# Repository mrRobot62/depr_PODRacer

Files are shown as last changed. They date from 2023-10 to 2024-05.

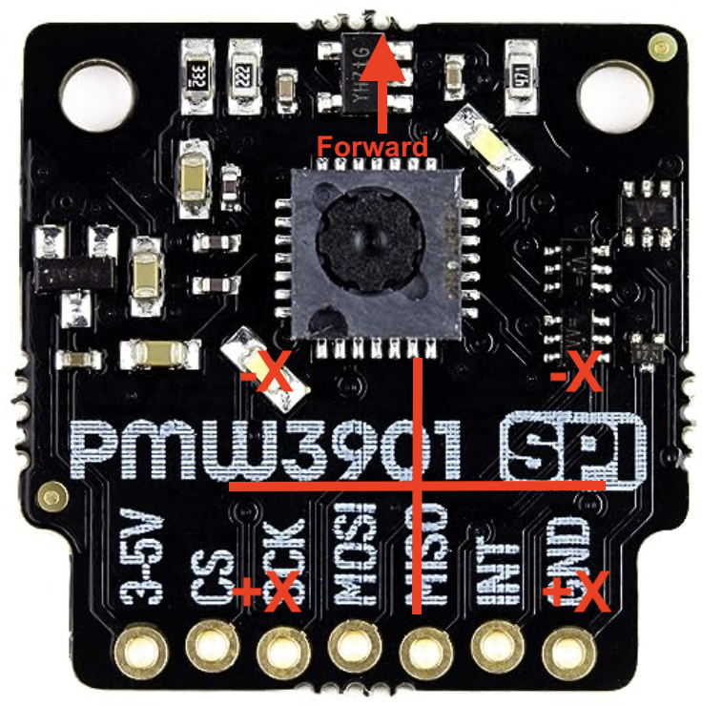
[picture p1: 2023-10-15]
doc/pmw3901_dir.png

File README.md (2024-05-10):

# OUTDATED
I decided to start more or less from scratch new. Current PODRacer-FW is implemented here: https://github.com/mrRobot62/PODRacerV3.git

# POD-Racer
```
.---------------------------------------------------------.
|_______________________________                          |
|___  __ \_  __ \__  __ \__  __ \_____ ___________________|
|__  /_/ /  / / /_  / / /_  /_/ /  __ `/  ___/  _ \_  ___/|
|_  ____// /_/ /_  /_/ /_  _, _// /_/ // /__ /  __/  /    |
|/_/     \____/ /_____/ /_/ |_| \__,_/ \___/ \___//_/     |
'---------------------------------------------------------'
```

# Hardware
## Transmitter (Taranis/TBS)
Channel configuration
- CH0 : roll axis		-> gimbal roll
- CH1 : pitch axis		-> gimbal pitch
- CH3 : FMS Impeller		-> gimbal throttle
- CH4 : yaw axis			-> gimbal yaw
- CH5 : arming/disarming-> switch
- CH6 : -> switch
- CH7 : -> switch
- CH8 : Hovering via POT S1	
## ToF-Sensors
- PMW3901 
- VL53LX1
- TF Mini LIDAR

# Software
# Arduino IDE 2.2.1

## ESP 32 - Datatype size
|Type|DataType|size (bytes)|
|---|---|:-:|
|Bool|bool|1|
|Char|char/int8-t|1|
|signed byte|int8_t|1|
|unsigned byte|uint8_t|1|
|int|int16_t|2|
|uint|uint16_t|2|
|long|long/int32_t|4|
|unsigned long|uint32_t|4|
|long64|int64_t|8|
|unsigned long64|uint64_t|8|
|Float|float|4/(8)|
|Double|double|8|
|String|char */String|variable|
|Bytes|uint8_t|variable|
||||

## Blackbox 
To store flight data, we use a SDCard with 4-8GB size. Every task use an internal data structure (every task use the same structure). This structure is used to store the data in a blackbox_<seqnumber>.bbd.

If PODRacer is armed a new blackbox file will be created, if disarmed the file is stored and closed on disk.
If disarming was not available (e.g. power off) the file is corrupted and not usable.

### Datetype-Struct (for every tasks usable)
```
#define NUMBER_CHANNELS 16
#define DATA_SIZE 8
typedef struct {
  uint16_t header;				   // fix to 0xFEEF
  long millis;                     // milliseconds
  // data
  uint8_t task_id;                 // produces by task-id
  uint8_t updated;                 // set by tasks
  uint8_t failsafe;                // set by receiver
  uint8_t lost_frame;              // set by receiver
  uint8_t levelA;                  // 1=normal, 2=depth (1=default)
  uint8_t levelB;                  // group_id 0=misc, 1=hover, 2=surfacedist, 3=OpticalFlow, 4=mixer, 
  uint16_t ch[NUMBER_CHANNELS];    // channel data (0=ch1, 1=ch2, 2=ch3, ...)
  //uint16_t ch_w[NUMBER_CHANNELS];// channel data (0=ch1, 1=ch2, 2=ch3, ...) WRITE 
  long ldata[DATA_SIZE];           // an be used for long values  
  double fdata[DATA_SIZE];         // can be used for float values
  double pid_rpyth[DATA_SIZE];     //(R/P/Y/T/H);
  uint16_t lock;                   // fix to 0xFF
  uint16_t crc;
} BlackBoxStruct;

typedef union {
  BlackBoxStruct data;
  uint8_t bytes [sizeof(BlackBoxStruct)];
} BBD;
```

Dump from a simulated data structure with fixed values
```
  bbd->data.header = 0xFEEF;
  bbd->data.millis = millis();
  bbd->data.task_id = 0x0A;
  bbd->data.updated = 0x0B;
  bbd->data.failsafe = 0xF0;
  bbd->data.lost_frame = 0xC0;
  bbd->data.groupA=0xB0;
  bbd->data.groupB=0xA0;
  bbd->data.crc = 0;  // for initializing!!!!! 
  for (uint8_t i=NUMBER_CHANNELS; i--;) {
    bbd->data.ch[i] = 1450;
  }
  for (uint8_t i=DATA_SIZE; i--;) {
    bbd->data.ldata[i] = -500;
    bbd->data.fdata[i] = 3.1415;
    bbd->data.pid_rpyth[i] = 1.0;
  }
  bbd->data.lock = 0xFF;
  uint16_t crc = FCRC16.ccitt((uint8_t*)bbd->bytes, sizeof(bbd));
  bbd->data.crc = crc;  
  sprintf(buffer, "CCITT-CRC: 0x%X", crc);
  Serial.println(buffer);
```
To understand how the struct is aligned you should understand [Data structure alignment](https://en.wikipedia.org/wiki/Data_structure_alignment)

### Short description
Bytes are stored with little endian. (LSB first, than MSB)

|Position| Data| Type |Padding| Info|
|---|:-:|:-:|:-:|---|
|0-1|EF FE|uint16_t|yes|header 2 bytes with padding|
|2-3|00 00|-|padding|2 padding bytes for uint16_t|
|4-7|1D 02 00 00|long|no|millis()|
|8-13|0A 0B F0 C0 B0 A0|uint8_t|no|7 Bytes uint8_t (task_id...groupB)|
|14-45|AA 05....|uint16_t|yes|16 channels a 2 Bytess, set to 1450(dec) 0x05AA|
|46,47|00 00|-|padding|2 padding bytes for uint16_t||
|48-79|0C FE FF FF|long|no|4 Bytes LData. Note: array of 8 long values|
|80-143|6F 12 83 C0 CA 21 09 40|double|no|8 Bytes FData. Note: array of 8 doubles values|
|144-207|00 00 00 00 00 00 F0 3F|double|no|8Bytes per pid_rpyth. Note: array of 8 doubles |
|208|FF|uint8_t|yes|lock byte|
|209|00|no|padding|1 padding byte|
|210-211|97 2C|uint16_t|yes|2 Bytes CRC|
|212-215|00 00 00 00 |-|padding| 4 Bytes padding|

```
-- dump-start (216 bytes) -------------------------
EF FE 00 00 1D 02 00 00 0A 0B F0 C0 B0 A0 AA 05 
AA 05 AA 05 AA 05 AA 05 AA 05 AA 05 AA 05 AA 05 
AA 05 AA 05 AA 05 AA 05 AA 05 AA 05 AA 05 00 00 
0C FE FF FF 0C FE FF FF 0C FE FF FF 0C FE FF FF 
0C FE FF FF 0C FE FF FF 0C FE FF FF 0C FE FF FF 
6F 12 83 C0 CA 21 09 40 6F 12 83 C0 CA 21 09 40 
6F 12 83 C0 CA 21 09 40 6F 12 83 C0 CA 21 09 40 
6F 12 83 C0 CA 21 09 40 6F 12 83 C0 CA 21 09 40 
6F 12 83 C0 CA 21 09 40 6F 12 83 C0 CA 21 09 40 
00 00 00 00 00 00 F0 3F 00 00 00 00 00 00 F0 3F 
00 00 00 00 00 00 F0 3F 00 00 00 00 00 00 F0 3F 
00 00 00 00 00 00 F0 3F 00 00 00 00 00 00 F0 3F 
00 00 00 00 00 00 F0 3F 00 00 00 00 00 00 F0 3F 
FF 00 97 2C 00 00 00 00 
-- dump-end ------------------------------------
```

## Debugging & Logging
SimpleLog include some output function to adjust log output. To avoid thousands of log messages, inside constants.h there are some `#define` statements to adjust the output. **Logging information will not be stored on SDCard !**

```
#define LOGLEVEL 3  // 3=Info, 4=Debug

//#define LOG_TASK_ALL
//#define LOG_TASK_RECEIVER
//#define LOG_TASK_ARBITRATE
#define LOG_TASK_OPTICALFLOW
//#define LOG_TASK_SURFACE1
//#define LOG_TASK_SURFACE2
#define USE_SERIAL_PLOTTER

``` 
- loglevel 3 (Info), 4=Debug messages
- **LOG_TASK_ALL:** if uncommented everything is logged
- **LOG_TASK_RECEIVER:** log only receiver output messages
- **LOG_TASK_ARBITRATE:** log only messages from Mixer
- **LOG_TASK_OPTICALFLOW:** log only messages from OpticalFlow class (PMW3901)
- **LOG_TASK_SURFACE1:** log only messages from TFMiniLidar
- **LOG_TASK_SURFACE2:** log only messages from VH53L1 ToF
- **USE_SERIAL_PLOTTER:** in combination of above directives you can produce nice SerialPlotter graphs

# Arduino Modules
- Bitcraze PMW391 v1.2 (ToF Sensor)
- Servo by Michael Margolis, v1.2.1
- PID by Brett Beauregard v1.2.0
- SimpleKalmanFilter by Denys Sene v0.1
- VL53LX1 by Pololu v1.3.1 (ToF Sensor)
- TFMPlus by Bud v1.5.0 (TFMini Lidar)
- SBUS Bolder FlightSystem by Brian Taylor v8.1.4 (Receiver)

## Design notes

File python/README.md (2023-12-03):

# PODRacer - Serial Reader

This python script is used to collect live data send by PODRacer FW.

The serial read recevie messages which are send via serial interface and store them into a csv file.

## Runtime Arguments
- --port : define your serial port. If locked, system ends
- --baud : default is 115200, it's possible to set a individual baud rate, must be the same as in fw.
- --tout : timeout, default is 5secs
- --opath : default is `data`, absolute path were file to store
- --delimter : default is ',' (comma), should be the same as in firmware
- --use_ts : if set, a current timestamp is set for filename (should be used !)
- --v : output verbosity

**Example**
```./serial_reader.py --port /dev/cu.usbserial-0001 ```

## CSV structure
```
TIME,TASK,GROUP,CH_R,CH_P,CH_Y,CH_H,CH_T,ARMING,AUX2,AUX3,float0,float1,float2,float3,float4,float5,float6,float7,ldata0,ldata1,ldata2,ldata3,ldata4,ldata5,ldata6,ldata7,pidRoll,pidPitch,pidYaw,pidThrust,pidHover,HOVER_MINIMAL_HEIGHT,HOVER_MIN_DISTANCE,HOVER_MAX_DISTANCE,CRC
```
- TIME : in milli seconds
- TASK : Task name
- GROUP : can be set by TASK - default should be 'UPD'. Is used to separate different output from a task
- CHR_R - CH-T : channel data which es send to receiver
- ARMING :  should allways 1
- AUX2+3 : data from AUX-_Channels
- float0-7 : depends on task, if a task contain several sensors (groups), can be splittet into several parts
- ldata0-7 : see float0-7 
- pidRPYTH : special pid values for channels
- HOVERxxx : constant values for hover task
- CRC : checksum
-

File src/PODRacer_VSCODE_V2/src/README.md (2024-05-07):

# PODRacer
A FPV 4 Motor copter construction with a fifth motor as thruster controlled by a flight controller with a BetaFlight firmware and a second PODRacer-FlightController based on an ESP32 with a specified firmware from this repo.

## Short summary of the base functionalities
### Betaflight-Flightcontroller
This FC is responsible for hovering, arming, disarming other saftey features. In Betaflight a preset should be used for heavy 5" copters to get a better performance for filters, PIDs ...
The base flight configuration is with ANGLE-mode enabled. In this case we will have more or less a self-stabilized copter

### general Channel-Mapping
* Channel 1 = ROLL
* Channel 2 = PITCH
* Channel 3 = THRUSTER (Throttle-Gimbal). This will spin impeller (5th) motor
* Channel 4 = Yaw
* Channel 5 = ARMING/DISARMING
* Channel 6 = HOVERING (POTI), this will spin motors 1-4 faster or slower
* Channel 7 = free
* Channel 8 = free
* 
### PODRacer-Flightcontroller
This FC handles all PODRacers specials. The FC controls several sensors and is responsible for hovering-height.

#### Tasks & Sensors
- Receiver-Task: This task will read an SBUS input signal, send this data (up to 16 Channels) to the firmware. Can write an SBUS-Signal to the BF-FC. The receiver is "man in the middle" between receiver and BF-FC
- Mixer-Task: this task collect all inputs form other tasks, mix them up, generate an output-data struture and send it back to the receiver (write-signal). The mixer implements a sub-sumption algorithm that will prioritize the tasks. Higher prioritised tasks will overwrite lower tasks. Example hovering is the lowes priority, Saftey-Task (not realy a task) but this have the hightest priority. SurfaceDistance sensor data are the hightest prioritized sensor data
- Hovering-Task: This is not a sensor. The PODRacer should hover in a height between 300-500mm over ground. With the POTI on the transmitter we start hovering. The sensors below with analyse the current heigt and correct the hovering signal send to the BF-FC
- Surface-Distance-Sensor: these are two sensors. A TFMini-LIDAR sensor at front bottom of the PODRacer and a second TOF-Sensor at bootom rear of the copter. The firmware anlayse the sensors inputs, calculate difference between target height and current height. The result is an input for the internal mixer task
- OpticalFlow-Sensor: this sensor is used to analyse if the PODRacer glides over ground during slow movements or if stops over ground. If an movement is recognized, the task calculate an opposite direction mix for roll, yaw, pitch axis and this information are input data for the mixer
- Steering-Task: This task do only some small adjustments if the PODRacer move in an arc and adjust roll/yaw/pid to get a smoother turn-alignment
  
#### Saftey
The arming-signal for the BF-FC is replaced by an PREVENT-Arming algorithm from the PODRacers FW. Arming is only allowed, if thruster is on min postion, hovering is on min postion and all other gimbals are in center position. If this is true, than arming is allowed. If armed, the for motors will spin and with the POTO the hovering (starting) is possible

## Main-Flightcontroller
any F405 or F722 controller, with latest Betaflight FW flashed

## PODRacers-Flightcontroller
an ESP32 WROOM (should running on other ESP32, but only tested with a WROOM)
flashed with latest PODRacer FW

# Transmitter configuration
We tested the system with transivers based on OpenTX. This description describe only what you have to do on an OpenTX FW (or equivalent Systems like EdgeTX).
Very important: current FW for PODRacer do only work with SBUS-protocol - no CRSF, nothing other !!! Please double check if your receiver is configured as an SBUS-Receiver

## Configure Input/Output channels

# Betaflight - configuration

## Configure Channels

# Thurster-ESC connected as an servo output
The ESC for the thruster-brushless motor is an single esc connected with the PWM-input pin on the LED_OUTPUT pin from the main flight controller.

# PODRacer FlightController
## Flashen

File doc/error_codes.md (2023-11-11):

# PODRacer Error codes
Error are stored in an uint8_t variable. To store for all tasks different error codes we use bit masks

## Bit-Mask
```
7 6 5 4 3 2 1
x x x x y y y
```

xxxx = TaskID 1-15
yyyy = Code 1-15

To set an error call inside a task `setError(getID(), 0x??);` 

## Codecs

|Task|TaskID|ErrorCode|Code|Info|
|---|:-:|:-:|:-:|---|
|TASK_HOVER|1|00010001|1|Receiver object missing|
|TASK_OPTICALFLOW|2|00100001|1|Receiver object missing|
|TASK_OPTICALFLOW|2|00100010|2|PMW3901 object missing|
|TASK_OPTICALFLOW|2|00100011|3|PID controller not initialized|
|TASK_OPTICALFLOW|2|00100100|4|flow->begin() failed|
||||||
||||||
||||||
||||||

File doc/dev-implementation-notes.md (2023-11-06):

# Implementierungs Hinweise

## 06.11.2023 BK
setError(), erweitert umd einen Parameter taskID & code.
Ein Fehler besteht nun aus zwei Teilen Bit0-Bit3 enthält den Code und Bit4-Bit7 die TaskID.
Somit können wir später in einer Auswertung deutlich einfacher Fehlercodes auswerten
Pro Tasks können 15 verschiedene ErrorCodes definiert werden
Insgesamt 16 Tasks können genutzt werden 

Beispiel: 
01010100  => Task 5 & Code 4
00010011  => Task 1, Code 3

## 05.11.2023 BK
Nachdem es mehrere Probleme mit Abstürzen gab, habe ich aktuell nur HOVERING/MIXER/RECEIVER aktiviert. Das primäre Problem mit Abstürzen lag an einem zu kleinen buffer innerhalb von SimpleLOG. Dieser intere Buffer habe ich auf 200 erhöht.

Durchstich gelungen ! Man kann nun sowohl in der Logausgabe als auch in Betaflight sehen, das sich der copter dreht/bewegt sobald man gearmt hat und mit dem Gimbal steuerbefehle sendet. Zum Versenden der Daten über SBUS muss zwingend wieder ein Mapping auf die 
channel_calibration Werte durchgeführt werden. Die Liste enthält
{MIN_SBUS, MAX_SBUS, GIMBAL_MIN, GIMBAL_MAX}
READ liest nun die SBUS signale und mapped diese auf GIMBAL_xxxxx.
WRITE macht es genau umgekehrt mapped von GIMBAL zurück auf SBUS
und dann funktioniert es auch mit BetaFlight :-) 

## 02.11.2023 BK
EmergencyTask implementiert (aber noch nicht getestet). Dieser Task wird in Main innerhalb der BlinkPatternFunction() aufgerufen um ein BlinkPattern zu setzen.

```
    if (emergency.isEmergencyStop()) {
      blink_pattern = PATTERN_EMERGENCY;
    } else if (receiver.isPreventArming() || emergency.isPreventArming()) {
      blink_pattern = PATTERN_PREVENTARMING;
    } else if (!receiver.isArmed() || emergency.isArmed()) {
      blink_pattern = PATTERN_DISARMED;
    }
```

## 01.11.2023 BK
MIXER gesplittet in _HoverMixer und _RPYMixer. In der update() Funktion von Mixer.cpp.
Zuerst wird _HoverMixer aufgerufen. Dieser Mixer nutzt die Daten aus HoverTask & SurfaceDistance
Anschließnd wird _RPYMixer aufgerufen.
Dieser Mixer wird entweder von FlowTask oder von SteeringTask genutzt.

Sind beide Sub-Mixer abgearbeitet werden die Daten in das zentralen Mixer-Struct kopiert und dem Receiver übergeben.

## 31.10.2023 BK
### Mixer leitet jetzt Hover Data zum Receiver durch
Wichtiger Schritt geschafft. Aus der Main-Methode, wird kann der Mixer nun den HoverTask "abfragen" und seine daten an den Receiver weiterleiten. Das ist ein wichtiger Schritt.

### Hovering-Task
setzt `_bbd.data.ch[HOVERING]` auf den POTI-Wert ist der Wert, ~~ändert sich der Wert zum vorherigen mal, dann wird
`_bbd.data.updated` auf `true` gesetzt~~ - HOVER setzt `_bbd.data.updated` immer auf true. Serial-Plotout zeigt nur geänderte Werte um ein Output-Overkill zu vermeiden

### Disarming - Blinking-Pattern
Blink-Pattern, wenn der PODRacer Disarmed ist (2x 250ms, 2x100ms wiederholden).

### PreventArming - Blinking-Pattern
Wenn _isPreventArming = true, dann wird ein schnell blinkendes Muster (1x100ms ON, 1x100ms OFF wiederholend) angezeigt. Das deutet dann darauf hin, das einer der Sticks oder Poti nicht korrekt sind und somit das Arming nicht möglich ist.

### PreventArming - BitMasking
Arming ist nur erlaubt wenn eine definierter Status vorhanden ist.
Es darf nur dann gearmed werden wenn:
* R/P/Y in CenterPosition
* Throttle & Thrust auf MIN-Position sind
* Wurde einmal erfolgreich gearmt und es wird disarmed dann muss anschließend wieder alles auf Center und Min stehen sonst ist kein arming möglich
  
> Vermutlich ist der Throttle-Poti oder der Thrust-Stick meistens nicht in der MIN-Position, das ist der Grund warum es 
so wichtig ist, das man nur armen kann, wenn es ungefährlich ist.

**Lösung:**
Verwendet wird eine armingMask. Hier werden nur die unteren 4Bits verwendet

* armingMask   0b0000 0000 (hier werden die Bits gesetzt)
* armingOKMask 0b0000 1010 (vergleich gegen dieses Muster)

**Kürzel**

- **ASO** = ArmingSwitchOFF
- **AS1** = ArmingSwitchON
- **SP1** = RPY=CP, T&H = MIN
- **SP0** = ein Stick/Poti ist nicht in CP oder MIN 

#### Beispiel 1 : Disarmed und Sticks in CP bzw. MIN, Ideal-Zustand
|Beispiel|Bit 3|Bit 2|Bit 1|Bit 0|Info|Maskierung|Arming|
|---|:-:|:-:|:-:|:-:|---|:-:|--:|
|-|0|0|0|0|intial|nein|nein|
|AS0+SP1|0|0|1|1|AS0 setzt B0, SP1 setzt B1|0011 & 1010 = 0011|nein|
|AS0+SP0|0|0|0|1|B0 bleibt, SP0+AS0 => B3=0 B1=0|0001 & 1010 =0001|nein|
|AS1+SP1|1|0|1|0|B3 durch AS1, SP1 setzt B2, AS1 reset B0|1010 & 1010=1010|ja|

#### Beispiel 2 : PODRacer war gearmed wird nun disarmed, Throttle nicht auf MIN 
|Beispiel|Bit 3|Bit 2|Bit 1|Bit 0|Info|Maskierung|Arming|
|---|:-:|:-:|:-:|:-:|---|:-:|--:|
|-|1|0|1|0|Arming aktiv|-|ja|
|AS0+SP0|0|0|0|1|wird disarmed, AS0 setzt B0|0001 & 1010 = 0001|nein|
|AS1+SP0|1|0|0|1|arming, AS1 setzt B3, SP0 reset B1, B0 unverändert|1001 & 1010 = 1001|nein|
|AS1+SP1|1|0|1|1|arming, AS1 setzt B3, SP1 set B1, B0 unverändert|1011 & 1010 = 1011|nein|
|AS0+SP1|0|0|1|0|disarming B3=0, reset B0, SP1 set B1|0010 & 1010 = 0010|nein|
|AS1+SP1|1|0|1|0|arming B3=1, SP1 set B1|0010 & 1010 = 0010|ja|

## 29.10.2023 BK

### Klasse Blackbox
Diese Klasse hängt an TaskAbstract dran und steht jedem Task zur Verfügung. Hierüber kann ein Datenstream auf die SDCard geschrieben werden. Ich mach das immer so, das ich bevor ich das in unserem Projekt einbaue mit Test-Sketches arbeite um eine Klasse so gut es geht zu testen. Dort funktioniert die Klasse Blackbox recht gut.

Im Test (Test-Sketch) läuft das, beim Aufruf wird immer eine neue Datei mit einer Sequenz-Nummer generiert. In diese wird auch reingeschrieben.

In unserer FW ist das Ganze zwar inkludiert aber ich muss das nach mit dem ARMING-SWITCH korrekt verbinden. Loggen macht ja nur Sinn, wenn auch gearmt ist.

> **Wichtig:** die SDCard wird wie der PMW3901 über SPI angeschlossen. Jedes SPI-Device benötigt eine eigene CS(Chip-Select PIN). Aktuell GPIO5 = PMW3901, GPIO32=SDCard (siehe constants.h)

### Neue typedef struct BBD
```
typedef struct {
  uint16_t header;
  long millis;                          // milliseconds
  // data
  uint8_t task_id;                      // produces by task-id
  bool updated;                         // set by tasks
  bool failsafe;                        // set by receiver
  bool lost_frame;                      // set by receiver
  bool armingState;                     // true=armed, false=disarmed
  uint8_t groupA;                       // can be used to group data 1. order
  uint8_t groupB;                       // can be used to group data 2. order
  uint16_t ch[NUMBER_CHANNELS];         // channel data (0=ch1, 1=ch2, 2=ch3, ...)
  //uint16_t ch_w[NUMBER_CHANNELS];       // channel data (0=ch1, 1=ch2, 2=ch3, ...) WRITE 
  long ldata[DATA_SIZE];          // an be used for long values  
  double fdata[DATA_SIZE];        // can be used for float values
  double pid_rpyth[DATA_SIZE];    //(R/P/Y/T/H);
  uint16_t crc;
} BlackBoxStruct;

typedef union {
  BlackBoxStruct data;
  byte bytes [sizeof(BlackBoxStruct)];
} BBD;

```

Diese Struktur stellt TaskAbstract grundlegend zur Verfügung für jeden abgeleiteten Task. Jeder Task nutzt nun diese Struktur und kann seine Informationen einfügen. Diese Informationen laufen über den Mixer an den Receiver und von dort zum FlightController.

Zusätzlich ist diese Struktur nun so aufgebaut, das auch die Klasse Blackbox damit arbeiten kann und exakt diese Struktur auf SDKarte kopiert

Beispiel für ein Dump dieser Struktur:
```
-- dump-start (216 bytes) -------------------------
EF FE 00 00 B4 01 00 00 0A 0B F0 C0 B0 A0 AA 05 
AA 05 AA 05 AA 05 AA 05 AA 05 AA 05 AA 05 AA 05 
AA 05 AA 05 AA 05 AA 05 AA 05 AA 05 AA 05 00 00 
0C FE FF FF 0C FE FF FF 0C FE FF FF 0C FE FF FF 
0C FE FF FF 0C FE FF FF 0C FE FF FF 0C FE FF FF 
6F 12 83 C0 CA 21 09 40 6F 12 83 C0 CA 21 09 40 
6F 12 83 C0 CA 21 09 40 6F 12 83 C0 CA 21 09 40 
6F 12 83 C0 CA 21 09 40 6F 12 83 C0 CA 21 09 40 
6F 12 83 C0 CA 21 09 40 6F 12 83 C0 CA 21 09 40 
00 00 00 00 00 00 F0 3F 00 00 00 00 00 00 F0 3F 
00 00 00 00 00 00 F0 3F 00 00 00 00 00 00 F0 3F 
00 00 00 00 00 00 F0 3F 00 00 00 00 00 00 F0 3F 
00 00 00 00 00 00 F0 3F 00 00 00 00 00 00 F0 3F 
FF 00 97 2C 00 00 00 00 
-- dump-end ------------------------------------

```
WICHIG: der Byte-Dump ist als Little-Endian gespeichert. Das heißt eine uint16_t value (z.B. 0xFEEF) wird im Byte-Stream als EF FE gespeichert.

#### BBD Detail-Informationen

* `uint16_t header`
	* ist immer 0xFEEF und dient als "Satz-Anfangs-kennzeichen"
* `bool updated`
	* **muss** von jedem Task gesetzt werden, wenn es updates in der ch-Liste setzt. Sonst ignoriert der Mixer das
* `bool armingState`
	* **sehr wichtig** für Tasks nur wenn der State TRUE ist, darf der Task Daten anpassen und updated auf TRUE setzen !
* `uint8_t groupA & groupB`
	* kann verwendet werden, wenn man seine Daten strukturieren möchte. Kann später ggf. über den Log-Analyzer gefiltert werden
* `double pid_rpyth[DATA_SIZE]`
	* hier können TASKs ihre PID Werte reinschreiben insgesamt stehen 8 freie Plätze zur Verfügung. In der Regel benötigt man 3-4 (ROLL;PITCH;YAW;?)
* `uint16_t ch[NUMBER_CHANNELS]`
	* hier schreiben die TASK ihre geänderten (in der Regel relative) Abweichungen zur CenterPoint (1500) rein. Ausnahme HOVER dieser Task schreibt absolute Werte. Aktuell nutzen wir nur CH1-CH8
* `long ldata[DATA_SIZE]`
	* TASK spezifische Werte (falls notwendig), die auch geloggt werden können. 8 unterschiedliche Long-Werte können pro Task gespeichert werden
* `double fdata[DATA_SIZE]`
	* dito zu ldata allerdings für Dezimal-Zahlen (3.1415)
* `bool fail_safe & lost_frames`
	* wird durch Receiver gesetzt

### Arming
Es ist wichtig, das das Ganze nur dann läuft, wenn der PODRacer auch „scharf“ geschaltet ist (ARMING) - mit dem roten Schalter. Wenn OFF, passiert nix, wenn ON, dann drehen die Rotoren etc.

Wichtig beim ARMEN ist das ein Check gemacht wird, das die Gimbals im Center sind, Throttel auf MIN und THRUST auch auf MIN stehen, erst dann darf gearmt werden ansonsten könnte es passieren, das der PODRacer direkt los brettert sobald man den Arming-Switch setzt :-O

Ich habe damit exemplarisch begonnen aber das klappt noch nicht perfekt. Hört sich einfach an aber in einem Task-Umfeld wo jeder Task unabhängig läuft ist das etwas tricky.

### Logging:
Beim Logging kann man jetzt auch den TASK-Namen mit angeben, dann wird im Log auch angezeigt von wem der Logeintrag kommt. Alle tasks haben im Constructor eine Variable _tname = „xxxxx“ stehen, der kann jetzt bei logger->info(„text“,_tname) als zweiter Parameter mit gegeben werden. Macht man das nicht erscheint ein „?“ in der Logausgabe zu diesem Logeintrag.
Commit
Ich habe Deine Änderungen gemerged aber ich befürchte da ist mir ein Fehler unterlaufen

`logger->info(buffer, _tname);`
Hier ein Bespiel es wird der Buffer ausgegeben und `_tname` im Log entsprechend ausgegeben
`10642| INFO|HOVER|H:1000` (hier HOVER)

`10642| INFO|    ?|H:1000` (wenn man _tname vergessen hat)

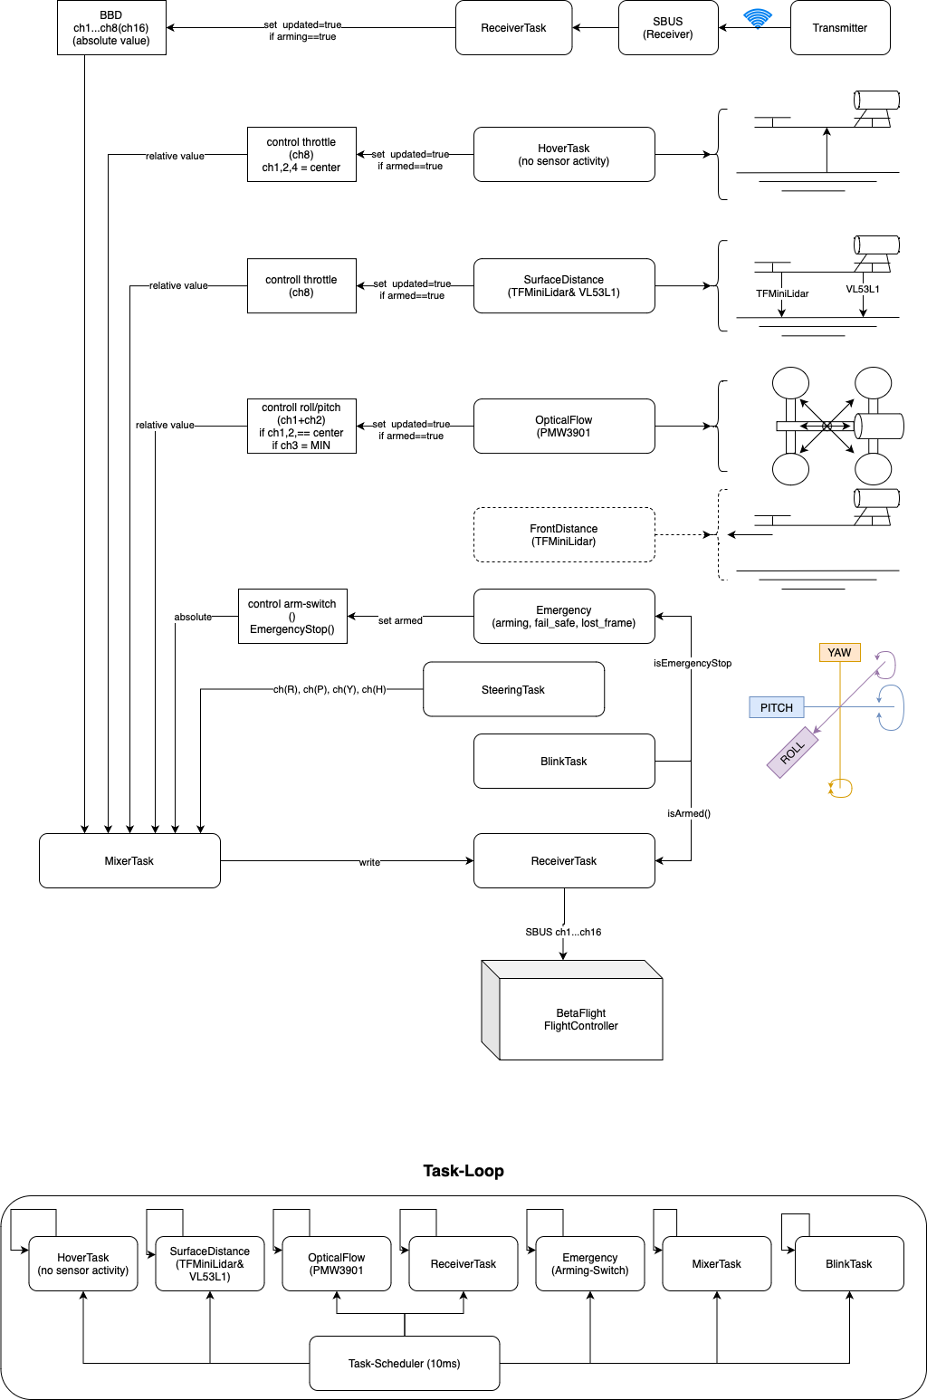
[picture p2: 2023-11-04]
doc/podracer_processing-Page-1.drawio.png

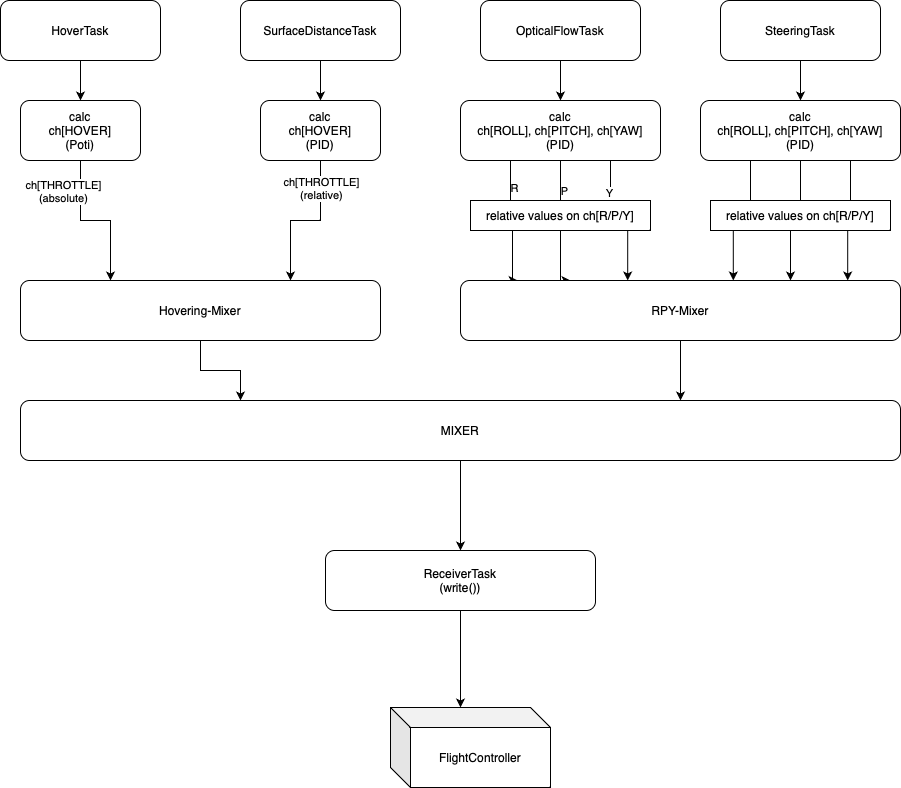
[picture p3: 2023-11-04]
doc/podracer_processing-Seite-2.drawio.png

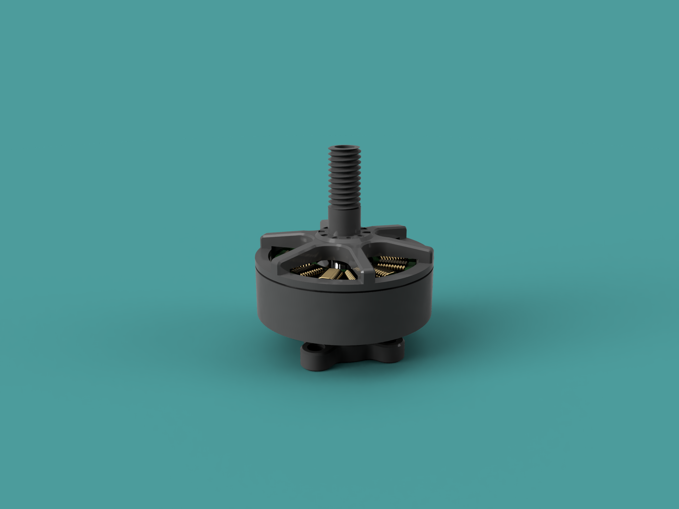
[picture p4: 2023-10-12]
stl/motor/2207 render.png

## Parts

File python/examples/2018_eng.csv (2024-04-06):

Overall rank | Score | GDP per capita | Social support | Healthy life expectancy | Freedom to make life choices | Generosity | Perceptions of corruption | Explained Happiness | Unexplained Happiness | Rank position | alpha2 | Continent | Country/Region | Population | alpha3
1 | 7.632 | 1.305 | 1.592 | 0.874 | 0.681 | 0.202 | 0.393 | 5.047 | 2.585 | Top | FI | Europe | Finland | 5470437.0 | FIN
2 | 7.594 | 1.456 | 1.582 | 0.861 | 0.686 | 0.286 | 0.34 | 5.210999999999999 | 2.383000000000001 | Top | NO | Europe | Norway | 5156450.0 | NOR
3 | 7.555 | 1.351 | 1.59 | 0.868 | 0.683 | 0.284 | 0.408 | 5.184 | 2.3709999999999996 | Top | DK | Europe | Denmark | 5655750.0 | DNK
4 | 7.495 | 1.343 | 1.644 | 0.914 | 0.677 | 0.353 | 0.138 | 5.069 | 2.426 | Top | IS | Europe | Iceland | 328170.0 | ISL
5 | 7.487 | 1.42 | 1.549 | 0.927 | 0.66 | 0.256 | 0.357 | 5.1690000000000005 | 2.3179999999999996 | Top | CH | Europe | Switzerland | 8183800.0 | CHE
6 | 7.441 | 1.361 | 1.488 | 0.878 | 0.638 | 0.333 | 0.295 | 4.993 | 2.4479999999999995 | Top | NL | Europe | Netherlands | 16881000.0 | NLD
7 | 7.328 | 1.33 | 1.532 | 0.896 | 0.653 | 0.321 | 0.291 | 5.023 | 2.3050000000000006 | Top | CA | North America | Canada | 35540419.0 | CAN
8 | 7.324 | 1.268 | 1.601 | 0.876 | 0.669 | 0.365 | 0.389 | 5.168 | 2.1559999999999997 | Top | NZ | Oceania | New Zealand | 4547900.0 | NZL
9 | 7.314 | 1.355 | 1.501 | 0.913 | 0.659 | 0.285 | 0.383 | 5.096 | 2.218 | Top | SE | Europe | Sweden | 9737521.0 | SWE
10 | 7.272 | 1.34 | 1.573 | 0.91 | 0.647 | 0.361 | 0.302 | 5.133 | 2.1390000000000002 | Top | AU | Oceania | Australia | 23696900.0 | AUS
11 | 7.19 | 1.244 | 1.433 | 0.888 | 0.464 | 0.262 | 0.082 | 4.373 | 2.817 | Top | GB | Europe | United Kingdom | 64105654.0 | GBR
12 | 7.139 | 1.341 | 1.504 | 0.891 | 0.617 | 0.242 | 0.224 | 4.819 | 2.3200000000000003 | Top | AT | Europe | Austria | 8527230.0 | AUT
13 | 7.072 | 1.01 | 1.459 | 0.817 | 0.632 | 0.143 | 0.101 | 4.162000000000001 | 2.9099999999999993 | Top | CR | North America | Costa Rica | 4713168.0 | CRI
14 | 6.977 | 1.448 | 1.583 | 0.876 | 0.614 | 0.307 | 0.306 | 5.134 | 1.843 | Top | IE | Europe | Ireland | 6378000.0 | IRL
15 | 6.965 | 1.34 | 1.474 | 0.861 | 0.586 | 0.273 | 0.28 | 4.814 | 2.151 | Top | DE | Europe | Germany | 80783000.0 | DEU
16 | 6.927 | 1.324 | 1.483 | 0.894 | 0.583 | 0.188 | 0.24 | 4.712000000000001 | 2.214999999999999 | Top | BE | Europe | Belgium | 11225469.0 | BEL
17 | 6.91 | 1.576 | 1.52 | 0.896 | 0.632 | 0.196 | 0.321 | 5.140999999999999 | 1.769000000000001 | Top | LU | Europe | Luxembourg | 549700.0 | LUX
18 | 6.886 | 1.398 | 1.471 | 0.819 | 0.547 | 0.291 | 0.133 | 4.659 | 2.2270000000000003 | Top | US | North America | United States | 319259000.0 | USA
19 | 6.814 | 1.301 | 1.559 | 0.883 | 0.533 | 0.354 | 0.272 | 4.902 | 1.912 | Top | IL | Asia | Israel | 8268400.0 | ISR
20 | 6.774 | 2.096 | 0.776 | 0.67 | 0.284 | 0.186 | 0.112 | 4.124 | 2.6500000000000004 | Top | AE | Asia | United Arab Emirates | 9446000.0 | ARE
21 | 6.711 | 1.233 | 1.489 | 0.854 | 0.543 | 0.064 | 0.034 | 4.2170000000000005 | 2.4939999999999998 | Top | CZ | Europe | Czech Republic | 10521600.0 | CZE
22 | 6.627 | 1.27 | 1.525 | 0.884 | 0.645 | 0.376 | 0.142 | 4.8420000000000005 | 1.7849999999999993 | Top | MT | Europe | Malta | 416055.0 | MLT
23 | 6.489 | 1.293 | 1.466 | 0.908 | 0.52 | 0.098 | 0.176 | 4.460999999999999 | 2.0280000000000005 | Top | FR | Europe | France | 66078000.0 | FRA
24 | 6.488 | 1.038 | 1.252 | 0.761 | 0.479 | 0.069 | 0.095 | 3.6940000000000004 | 2.794 | Top | MX | North America | Mexico | 119713203.0 | MEX
25 | 6.476 | 1.131 | 1.331 | 0.808 | 0.431 | 0.197 | 0.061 | 3.9589999999999996 | 2.5170000000000003 | Top | CL | South America | Chile | 17819054.0 | CHL
26 | 6.441 | 1.365 | 1.436 | 0.857 | 0.418 | 0.151 | 0.078 | 4.305000000000001 | 2.1359999999999992 | Top | TW | Asia | Taiwan | 23424615.0 | TWN
27 | 6.43 | 1.112 | 1.438 | 0.759 | 0.597 | 0.125 | 0.063 | 4.093999999999999 | 2.3360000000000003 | Top | PA | North America | Panama | 3713312.0 | PAN
28 | 6.419 | 0.986 | 1.474 | 0.675 | 0.493 | 0.11 | 0.088 | 3.8259999999999996 | 2.593 | Top | BR | South America | Brazil | 203586000.0 | BRA
29 | 6.388 | 1.073 | 1.468 | 0.744 | 0.57 | 0.062 | 0.054 | 3.9709999999999996 | 2.4170000000000003 | Top | AR | South America | Argentina | 42669500.0 | ARG
30 | 6.382 | 0.781 | 1.268 | 0.608 | 0.604 | 0.179 | 0.071 | 3.511 | 2.8709999999999996 | Top | GT | North America | Guatemala | 15806675.0 | GTM
31 | 6.379 | 1.093 | 1.459 | 0.771 | 0.625 | 0.13 | 0.155 | 4.2330000000000005 | 2.145999999999999 | Top | UY | South America | Uruguay | 3404189.0 | URY
32 | 6.374 | 1.649 | 1.303 | 0.748 | 0.654 | 0.256 | 0.171 | 4.781000000000001 | 1.592999999999999 | Top | QA | Asia | Qatar | 2269672.0 | QAT
33 | 6.371 | 1.379 | 1.331 | 0.633 | 0.509 | 0.098 | 0.127 | 4.077 | 2.2940000000000005 | Top | SA | Asia | Saudi Arabia | 30770375.0 | SAU
34 | 6.343 | 1.529 | 1.451 | 1.008 | 0.631 | 0.261 | 0.457 | 5.337 | 1.0060000000000002 | Top | SG | Asia | Singapore | 5469700.0 | SGP
35 | 6.322 | 1.161 | 1.258 | 0.669 | 0.356 | 0.311 | 0.059 | 3.814 | 2.508 | Top | MY | Asia | Malaysia | 30430500.0 | MYS
36 | 6.31 | 1.251 | 1.538 | 0.965 | 0.449 | 0.142 | 0.074 | 4.419 | 1.891 | Top | ES | Europe | Spain | 46507760.0 | ESP
37 | 6.26 | 0.96 | 1.439 | 0.635 | 0.531 | 0.099 | 0.039 | 3.7030000000000003 | 2.5569999999999995 | Top | CO | South America | Colombia | 47907800.0 | COL
38 | 6.192 | 1.223 | 1.492 | 0.564 | 0.575 | 0.171 | 0.019 | 4.0440000000000005 | 2.1479999999999997 | Top | TT | North America | Trinidad and Tobago | 1328019.0 | TTO
39 | 6.173 | 1.21 | 1.537 | 0.776 | 0.354 | 0.118 | 0.014 | 4.0089999999999995 | 2.1640000000000006 | Top | SK | Europe | Slovakia | 5415949.0 | SVK
40 | 6.167 | 0.806 | 1.231 | 0.639 | 0.461 | 0.065 | 0.082 | 3.284 | 2.883 | Top | SV | North America | El Salvador | 6401240.0 | SLV
41 | 6.141 | 0.668 | 1.319 | 0.7 | 0.527 | 0.208 | 0.128 | 3.5500000000000007 | 2.5909999999999993 | Top | NI | North America | Nicaragua | 6134270.0 | NIC
42 | 6.123 | 1.176 | 1.448 | 0.781 | 0.546 | 0.108 | 0.064 | 4.122999999999999 | 2.000000000000001 | Top | PL | Europe | Poland | 38496000.0 | POL
43 | 6.105 | 1.338 | 1.366 | 0.698 | 0.594 | 0.243 | 0.123 | 4.362 | 1.7430000000000003 | Top | BH | Asia | Bahrain | 1316500.0 | BHR
44 | 6.096 | 0.719 | 1.584 | 0.605 | 0.724 | 0.328 | 0.259 | 4.218999999999999 | 1.8770000000000007 | Top | UZ | Asia | Uzbekistan | 30492800.0 | UZB
45 | 6.083 | 1.474 | 1.301 | 0.675 | 0.554 | 0.167 | 0.106 | 4.277 | 1.806 | Top | KW | Asia | Kuwait | 3268431.0 | KWT
46 | 6.072 | 1.016 | 1.417 | 0.707 | 0.637 | 0.364 | 0.029 | 4.17 | 1.9020000000000001 | Top | TH | Asia | Thailand | 64871000.0 | THA
47 | 6.0 | 1.264 | 1.501 | 0.946 | 0.281 | 0.137 | 0.028 | 4.156999999999999 | 1.8430000000000009 | Top | IT | Europe | Italy | 60769102.0 | ITA
48 | 5.973 | 0.889 | 1.33 | 0.736 | 0.556 | 0.114 | 0.12 | 3.745 | 2.2279999999999998 | Top | EC | South America | Ecuador | 15888900.0 | ECU
49 | 5.956 | 0.807 | 1.101 | 0.474 | 0.593 | 0.183 | 0.089 | 3.2469999999999994 | 2.709000000000001 | Top | BZ | North America | Belize | 349728.0 | BLZ
50 | 5.952 | 1.197 | 1.527 | 0.716 | 0.35 | 0.026 | 0.006 | 3.822 | 2.13 | Top | LT | Europe | Lithuania | 2927310.0 | LTU
51 | 5.948 | 1.219 | 1.506 | 0.856 | 0.633 | 0.16 | 0.051 | 4.425000000000001 | 1.5229999999999997 | Top | SI | Europe | Slovenia | 2064966.0 | SVN
52 | 5.945 | 1.116 | 1.219 | 0.726 | 0.528 | 0.088 | 0.001 | 3.678 | 2.2670000000000003 | Top | RO | Europe | Romania | 19942642.0 | ROU
53 | 5.933 | 1.148 | 1.454 | 0.671 | 0.363 | 0.092 | 0.066 | 3.7939999999999996 | 2.1390000000000002 | Top | LV | Europe | Latvia | 1991800.0 | LVA
54 | 5.915 | 1.294 | 1.462 | 0.988 | 0.553 | 0.079 | 0.15 | 4.526000000000001 | 1.3889999999999993 | Top | JP | Asia | Japan | 127080000.0 | JPN
55 | 5.891 | 1.09 | 1.387 | 0.684 | 0.584 | 0.245 | 0.05 | 4.040000000000001 | 1.850999999999999 | Top | MU | Africa | Mauritius | 1261208.0 | MUS
56 | 5.89 | 0.819 | 1.493 | 0.693 | 0.575 | 0.096 | 0.031 | 3.7070000000000003 | 2.1829999999999994 | Top | JM | North America | Jamaica | 2717991.0 | JAM
57 | 5.875 | 1.266 | 1.204 | 0.955 | 0.244 | 0.175 | 0.051 | 3.8949999999999996 | 1.9800000000000004 | Top | KR | Asia | South Korea | 50423955.0 | KOR
58 | 5.835 | 1.229 | 1.211 | 0.909 | 0.495 | 0.179 | 0.154 | 4.1770000000000005 | 1.6579999999999995 | Top | CY | Asia | Cyprus | 858000.0 | CYP
59 | 5.81 | 1.151 | 1.479 | 0.599 | 0.399 | 0.065 | 0.025 | 3.718 | 2.0919999999999996 | Top | RU | Europe | Russia | 146233000.0 | RUS
60 | 5.79 | 1.143 | 1.516 | 0.631 | 0.454 | 0.148 | 0.121 | 4.013 | 1.7770000000000001 | Top | KZ | Asia | Kazakhstan | 17377800.0 | KAZ
62 | 5.752 | 0.751 | 1.223 | 0.508 | 0.606 | 0.141 | 0.054 | 3.283 | 2.469 | Top | BO | South America | Bolivia | 10027254.0 | BOL
63 | 5.739 | 1.2 | 1.532 | 0.737 | 0.553 | 0.086 | 0.174 | 4.282000000000001 | 1.456999999999999 | Top | EE | Europe | Estonia | 1315819.0 | EST
64 | 5.681 | 0.835 | 1.522 | 0.615 | 0.541 | 0.162 | 0.074 | 3.749 | 1.932 | Top | PY | South America | Paraguay | 6893727.0 | PRY
65 | 5.663 | 0.934 | 1.249 | 0.674 | 0.53 | 0.092 | 0.034 | 3.5130000000000003 | 2.15 | Top | PE | South America | Peru | 30814175.0 | PER
66 | 5.662 | 0.855 | 1.23 | 0.578 | 0.448 | 0.274 | 0.023 | 3.408 | 2.254 | Top | XK | Europe | Kosovo | 1795666.0 | XKX
67 | 5.64 | 0.657 | 1.301 | 0.62 | 0.232 | 0.171 | 0.0 | 2.981 | 2.659 | Top | MD | Europe | Moldova | 3557600.0 | MDA
68 | 5.636 | 1.016 | 1.533 | 0.517 | 0.417 | 0.199 | 0.037 | 3.7189999999999994 | 1.9170000000000007 | Top | TM | Asia | Turkmenistan | 5838064.0 | TKM
69 | 5.62 | 1.171 | 1.401 | 0.732 | 0.259 | 0.061 | 0.022 | 3.646 | 1.9740000000000002 | Top | HU | Europe | Hungary | 9879000.0 | HUN
70 | 5.566 | 0.985 | 1.35 | 0.553 | 0.496 | 0.116 | 0.148 | 3.648 | 1.9179999999999997 | Top | LY | Africa | Libya | 6253000.0 | LBY
71 | 5.524 | 0.775 | 1.312 | 0.513 | 0.643 | 0.12 | 0.105 | 3.4680000000000004 | 2.0559999999999996 | Top | PH | Asia | Philippines | 100697400.0 | PHL
72 | 5.504 | 0.62 | 1.205 | 0.622 | 0.459 | 0.197 | 0.074 | 3.177 | 2.3269999999999995 | Top | HN | North America | Honduras | 8725111.0 | HND
73 | 5.483 | 1.039 | 1.498 | 0.7 | 0.307 | 0.101 | 0.154 | 3.799 | 1.6839999999999997 | Top | BY | Europe | Belarus | 9475100.0 | BLR
74 | 5.483 | 1.148 | 1.38 | 0.686 | 0.324 | 0.106 | 0.109 | 3.7529999999999992 | 1.7300000000000004 | Top | TR | Asia | Turkey | 76667864.0 | TUR
75 | 5.472 | 0.652 | 0.81 | 0.424 | 0.334 | 0.216 | 0.113 | 2.5490000000000004 | 2.923 | Top | PK | Asia | Pakistan | 188410000.0 | PAK
76 | 5.43 | 1.405 | 1.29 | 1.03 | 0.524 | 0.246 | 0.291 | 4.786000000000001 | 0.6439999999999984 | Top | HK | Asia | Hong Kong | 7234800.0 | HKG
77 | 5.41 | 1.188 | 1.429 | 0.884 | 0.562 | 0.055 | 0.017 | 4.135 | 1.2750000000000004 | Top | PT | Europe | Portugal | 10477800.0 | PRT
78 | 5.398 | 0.975 | 1.369 | 0.685 | 0.288 | 0.134 | 0.043 | 3.4939999999999998 | 1.904 | Top | RS | Europe | Serbia | 7186862.0 | SRB
79 | 5.358 | 1.154 | 1.202 | 0.879 | 0.131 | 0.0 | 0.044 | 3.4099999999999997 | 1.948 | Bottom | GR | Europe | Greece | 10992589.0 | GRC
80 | 5.358 | 0.965 | 1.179 | 0.785 | 0.503 | 0.214 | 0.136 | 3.7820000000000005 | 1.5759999999999992 | Bottom | LB | Asia | Lebanon | 4104000.0 | LBN
81 | 5.347 | 1.017 | 1.279 | 0.729 | 0.259 | 0.111 | 0.081 | 3.476 | 1.8710000000000004 | Bottom | ME | Europe | Montenegro | 627809.0 | MNE
82 | 5.321 | 1.115 | 1.161 | 0.737 | 0.38 | 0.12 | 0.039 | 3.552 | 1.7689999999999997 | Bottom | HR | Europe | Croatia | 4267558.0 | HRV
83 | 5.302 | 0.982 | 1.441 | 0.614 | 0.578 | 0.12 | 0.106 | 3.8409999999999997 | 1.4609999999999999 | Bottom | DO | North America | Dominican Republic | 10378267.0 | DOM
84 | 5.295 | 0.979 | 1.154 | 0.687 | 0.077 | 0.055 | 0.135 | 3.0870000000000006 | 2.2079999999999993 | Bottom | DZ | Africa | Algeria | 38700000.0 | DZA
85 | 5.254 | 0.779 | 0.797 | 0.669 | 0.46 | 0.026 | 0.074 | 2.8049999999999997 | 2.449 | Bottom | MA | Africa | Morocco | 33465000.0 | MAR
86 | 5.246 | 0.989 | 1.142 | 0.799 | 0.597 | 0.029 | 0.103 | 3.659 | 1.5870000000000006 | Bottom | CN | Asia | China | 1367110000.0 | CHN
87 | 5.201 | 1.024 | 1.161 | 0.603 | 0.43 | 0.031 | 0.176 | 3.4250000000000007 | 1.775999999999999 | Bottom | AZ | Asia | Azerbaijan | 9552500.0 | AZE
88 | 5.199 | 0.474 | 1.166 | 0.598 | 0.292 | 0.187 | 0.034 | 2.7509999999999994 | 2.4480000000000004 | Bottom | TJ | Asia | Tajikistan | 8161000.0 | TJK
89 | 5.185 | 0.959 | 1.239 | 0.691 | 0.394 | 0.173 | 0.052 | 3.508 | 1.6769999999999996 | Bottom | MK | Europe | Macedonia | 2085051.0 | MKD
90 | 5.161 | 0.822 | 1.265 | 0.645 | 0.468 | 0.13 | 0.134 | 3.4639999999999995 | 1.697 | Bottom | JO | Asia | Jordan | 6666960.0 | JOR
91 | 5.155 | 0.689 | 1.172 | 0.048 | 0.462 | 0.201 | 0.032 | 2.604 | 2.551 | Bottom | NG | Africa | Nigeria | 178517000.0 | NGA
92 | 5.131 | 0.53 | 1.416 | 0.594 | 0.54 | 0.281 | 0.035 | 3.3960000000000004 | 1.7349999999999999 | Bottom | KG | Asia | Kyrgyz Republic | 5776570.0 | KGZ
93 | 5.129 | 0.915 | 1.078 | 0.758 | 0.28 | 0.216 | 0.0 | 3.2470000000000008 | 1.8819999999999988 | Bottom | BA | Europe | Bosnia and Herzegovina | 3791622.0 | BIH
94 | 5.125 | 0.914 | 1.517 | 0.575 | 0.395 | 0.253 | 0.032 | 3.6860000000000004 | 1.4389999999999996 | Bottom | MN | Asia | Mongolia | 2987733.0 | MNG
95 | 5.103 | 0.715 | 1.365 | 0.702 | 0.618 | 0.177 | 0.079 | 3.656 | 1.4469999999999996 | Bottom | VN | Asia | Vietnam | 89708900.0 | VNM
96 | 5.093 | 0.899 | 1.215 | 0.522 | 0.538 | 0.484 | 0.018 | 3.676 | 1.4169999999999998 | Bottom | ID | Asia | Indonesia | 252164800.0 | IDN
97 | 5.082 | 0.796 | 1.335 | 0.527 | 0.541 | 0.364 | 0.171 | 3.734 | 1.3479999999999999 | Bottom | BT | Asia | Bhutan | 755030.0 | BTN
98 | 4.982 | 0.0 | 0.712 | 0.115 | 0.674 | 0.238 | 0.282 | 2.021 | 2.9610000000000003 | Bottom | SO | Africa | Somalia | 10806000.0 | SOM
99 | 4.975 | 0.535 | 0.891 | 0.182 | 0.454 | 0.183 | 0.043 | 2.2880000000000003 | 2.6869999999999994 | Bottom | CM | Africa | Cameroon | 20386799.0 | CMR
100 | 4.933 | 1.054 | 1.515 | 0.712 | 0.359 | 0.064 | 0.009 | 3.7129999999999996 | 1.2200000000000002 | Bottom | BG | Europe | Bulgaria | 7245677.0 | BGR
101 | 4.88 | 0.425 | 1.228 | 0.539 | 0.526 | 0.302 | 0.078 | 3.098 | 1.782 | Bottom | NP | Asia | Nepal | 27646053.0 | NPL
102 | 4.806 | 0.996 | 1.469 | 0.657 | 0.133 | 0.056 | 0.052 | 3.363 | 1.443 | Bottom | VE | South America | Venezuela | 30206307.0 | VEN
103 | 4.758 | 1.036 | 1.164 | 0.404 | 0.356 | 0.032 | 0.052 | 3.044 | 1.714 | Bottom | GA | Africa | Gabon | 1711000.0 | GAB
104 | 4.743 | 0.642 | 1.217 | 0.602 | 0.266 | 0.086 | 0.076 | 2.889 | 1.8540000000000005 | Bottom | PS | Asia | Palestine | 5091819.0 | PSE
105 | 4.724 | 0.94 | 1.41 | 0.33 | 0.516 | 0.103 | 0.056 | 3.355 | 1.3690000000000002 | Bottom | ZA | Africa | South Africa | 54002000.0 | ZAF
106 | 4.707 | 1.059 | 0.771 | 0.691 | 0.459 | 0.282 | 0.129 | 3.391 | 1.3159999999999998 | Bottom | IR | Asia | Iran | 77966400.0 | IRN
107 | 4.671 | 0.541 | 0.872 | 0.08 | 0.467 | 0.146 | 0.103 | 2.2090000000000005 | 2.4619999999999997 | Bottom | CI | Africa | Cote d'Ivoire | 26378275.0 | CIV
108 | 4.657 | 0.592 | 0.896 | 0.337 | 0.499 | 0.212 | 0.029 | 2.565 | 2.092 | Bottom | GH | Africa | Ghana | 27043093.0 | GHA
109 | 4.631 | 0.429 | 1.117 | 0.433 | 0.406 | 0.138 | 0.082 | 2.605 | 2.0260000000000002 | Bottom | SN | Africa | Senegal | 13508715.0 | SEN
110 | 4.623 | 0.72 | 1.034 | 0.441 | 0.626 | 0.23 | 0.174 | 3.2249999999999996 | 1.3980000000000006 | Bottom | LA | Asia | Laos | 6693300.0 | LAO
111 | 4.592 | 0.9 | 0.906 | 0.69 | 0.271 | 0.04 | 0.063 | 2.87 | 1.7219999999999995 | Bottom | TN | Africa | Tunisia | 10982754.0 | TUN
112 | 4.586 | 0.916 | 0.817 | 0.79 | 0.419 | 0.149 | 0.032 | 3.123 | 1.463 | Bottom | AL | Europe | Albania | 2895947.0 | ALB
113 | 4.571 | 0.256 | 0.813 | 0.0 | 0.355 | 0.238 | 0.053 | 1.7149999999999999 | 2.856 | Bottom | SL | Africa | Sierra Leone | 6205000.0 | SLE
114 | 4.559 | 0.682 | 0.811 | 0.343 | 0.514 | 0.091 | 0.077 | 2.5180000000000002 | 2.041 | Bottom | CG | Africa | Congo Republic | 5244362.0 | COG
115 | 4.5 | 0.532 | 0.85 | 0.579 | 0.58 | 0.153 | 0.144 | 2.838 | 1.662 | Bottom | BD | Asia | Bangladesh | 157486000.0 | BGD
116 | 4.471 | 0.918 | 1.314 | 0.672 | 0.585 | 0.307 | 0.05 | 3.846 | 0.625 | Bottom | LK | Asia | Sri Lanka | 20277597.0 | LKA
117 | 4.456 | 1.01 | 0.971 | 0.536 | 0.304 | 0.148 | 0.095 | 3.064 | 1.3920000000000003 | Bottom | IQ | Asia | Iraq | 36004552.0 | IRQ
118 | 4.447 | 0.37 | 1.233 | 0.152 | 0.367 | 0.139 | 0.056 | 2.317 | 2.13 | Bottom | ML | Africa | Mali | 15768000.0 | MLI
119 | 4.441 | 0.874 | 1.281 | 0.365 | 0.519 | 0.051 | 0.064 | 3.154 | 1.287 | Bottom | NA | Africa | Namibia | 2113077.0 | NAM
120 | 4.433 | 0.549 | 1.088 | 0.457 | 0.696 | 0.256 | 0.065 | 3.111 | 1.3219999999999996 | Bottom | KH | Asia | Cambodia | 15184116.0 | KHM
121 | 4.424 | 0.314 | 1.097 | 0.254 | 0.312 | 0.175 | 0.128 | 2.2800000000000002 | 2.144 | Bottom | BF | Africa | Burkina Faso | 17322796.0 | BFA
122 | 4.419 | 0.885 | 1.025 | 0.553 | 0.312 | 0.092 | 0.107 | 2.974 | 1.4449999999999994 | Bottom | EG | Africa | Egypt | 87668100.0 | EGY
123 | 4.417 | 0.198 | 0.902 | 0.173 | 0.531 | 0.206 | 0.158 | 2.168 | 2.2489999999999997 | Bottom | MZ | Africa | Mozambique | 25041922.0 | MOZ
124 | 4.41 | 0.493 | 1.048 | 0.454 | 0.504 | 0.352 | 0.055 | 2.9059999999999997 | 1.5040000000000004 | Bottom | KE | Africa | Kenya | 41800000.0 | KEN
125 | 4.377 | 0.562 | 1.047 | 0.295 | 0.503 | 0.221 | 0.082 | 2.71 | 1.6669999999999998 | Bottom | ZM | Africa | Zambia | 15023315.0 | ZMB
126 | 4.356 | 0.557 | 1.245 | 0.292 | 0.129 | 0.134 | 0.093 | 2.4499999999999997 | 1.9060000000000001 | Bottom | MR | Africa | Mauritania | 3545620.0 | MRT
127 | 4.35 | 0.308 | 0.95 | 0.391 | 0.452 | 0.22 | 0.146 | 2.467 | 1.8829999999999996 | Bottom | ET | Africa | Ethiopia | 87952991.0 | ETH
128 | 4.34 | 0.853 | 0.592 | 0.643 | 0.375 | 0.038 | 0.215 | 2.7159999999999997 | 1.624 | Bottom | GE | Asia | Georgia | 4490500.0 | GEO
129 | 4.321 | 0.816 | 0.99 | 0.666 | 0.26 | 0.077 | 0.028 | 2.837 | 1.4839999999999995 | Bottom | AM | Asia | Armenia | 3009800.0 | ARM
130 | 4.308 | 0.682 | 1.174 | 0.429 | 0.58 | 0.598 | 0.178 | 3.6409999999999996 | 0.6670000000000003 | Bottom | MM | Asia | Myanmar | 53708318.0 | MMR
131 | 4.301 | 0.358 | 0.907 | 0.053 | 0.189 | 0.181 | 0.06 | 1.7480000000000002 | 2.553 | Bottom | TD | Africa | Chad | 13211000.0 | TCD
132 | 4.245 | 0.069 | 1.136 | 0.204 | 0.312 | 0.197 | 0.052 | 1.97 | 2.2750000000000004 | Bottom | CD | Africa | DR Congo | 69360000.0 | COD
133 | 4.19 | 0.721 | 0.747 | 0.485 | 0.539 | 0.172 | 0.093 | 2.757 | 1.4330000000000003 | Bottom | IN | Asia | India | 1263930000.0 | IND
134 | 4.166 | 0.131 | 0.867 | 0.221 | 0.39 | 0.175 | 0.099 | 1.883 | 2.2830000000000004 | Bottom | NE | Africa | Niger | 17138707.0 | NER
135 | 4.161 | 0.322 | 1.09 | 0.237 | 0.45 | 0.259 | 0.061 | 2.419 | 1.7419999999999995 | Bottom | UG | Africa | Uganda | 34856813.0 | UGA
136 | 4.141 | 0.378 | 0.372 | 0.24 | 0.44 | 0.163 | 0.067 | 1.66 | 2.481 | Bottom | BJ | Africa | Benin | 9988068.0 | BEN
137 | 4.139 | 0.605 | 1.24 | 0.312 | 0.016 | 0.134 | 0.082 | 2.389 | 1.7500000000000004 | Bottom | SD | Africa | Sudan | 37289406.0 | SDN
138 | 4.103 | 0.793 | 1.413 | 0.609 | 0.163 | 0.187 | 0.011 | 3.1759999999999997 | 0.927 | Bottom | UA | Europe | Ukraine | 42973696.0 | UKR
139 | 3.999 | 0.259 | 0.474 | 0.253 | 0.434 | 0.158 | 0.101 | 1.6789999999999998 | 2.3200000000000003 | Bottom | TG | Africa | Togo | 6993000.0 | TGO
140 | 3.964 | 0.344 | 0.792 | 0.211 | 0.394 | 0.185 | 0.094 | 2.02 | 1.944 | Bottom | GN | Africa | Guinea | 10628972.0 | GIN
141 | 3.808 | 0.472 | 1.215 | 0.079 | 0.423 | 0.116 | 0.112 | 2.4170000000000003 | 1.3909999999999996 | Bottom | LS | Africa | Lesotho | 2098000.0 | LSO
142 | 3.795 | 0.73 | 1.125 | 0.269 | 0.0 | 0.079 | 0.061 | 2.2640000000000002 | 1.5309999999999997 | Bottom | AO | Africa | Angola | 24383301.0 | AGO
143 | 3.774 | 0.262 | 0.908 | 0.402 | 0.221 | 0.155 | 0.049 | 1.997 | 1.777 | Bottom | MG | Africa | Madagascar | 21842167.0 | MDG
144 | 3.692 | 0.357 | 1.094 | 0.248 | 0.406 | 0.132 | 0.099 | 2.3360000000000003 | 1.3559999999999999 | Bottom | ZW | Africa | Zimbabwe | 13061239.0 | ZWE
145 | 3.632 | 0.332 | 0.537 | 0.255 | 0.085 | 0.191 | 0.036 | 1.4360000000000002 | 2.1959999999999997 | Bottom | AF | Asia | Afghanistan | 26023100.0 | AFG
146 | 3.59 | 1.017 | 1.174 | 0.417 | 0.557 | 0.042 | 0.092 | 3.2989999999999995 | 0.29100000000000037 | Bottom | BW | Africa | Botswana | 2024904.0 | BWA
147 | 3.587 | 0.186 | 0.541 | 0.306 | 0.531 | 0.21 | 0.08 | 1.854 | 1.733 | Bottom | MW | Africa | Malawi | 15805239.0 | MWI
148 | 3.582 | 0.315 | 0.714 | 0.289 | 0.025 | 0.392 | 0.104 | 1.839 | 1.7429999999999999 | Bottom | HT | North America | Haiti | 10745665.0 | HTI
149 | 3.495 | 0.076 | 0.858 | 0.267 | 0.419 | 0.206 | 0.03 | 1.856 | 1.639 | Bottom | LR | Africa | Liberia | 4397000.0 | LBR
150 | 3.462 | 0.689 | 0.382 | 0.539 | 0.088 | 0.376 | 0.144 | 2.218 | 1.2440000000000002 | Bottom | SY | Asia | Syria | 22964324.0 | SYR
151 | 3.408 | 0.332 | 0.896 | 0.4 | 0.636 | 0.2 | 0.444 | 2.9080000000000004 | 0.49999999999999956 | Bottom | RW | Africa | Rwanda | 10996891.0 | RWA
152 | 3.355 | 0.442 | 1.073 | 0.343 | 0.244 | 0.083 | 0.064 | 2.249 | 1.1059999999999999 | Bottom | YE | Asia | Yemen | 25956000.0 | YEM
153 | 3.303 | 0.455 | 0.991 | 0.381 | 0.481 | 0.27 | 0.097 | 2.675 | 0.6280000000000001 | Bottom | TZ | Africa | Tanzania | 47421786.0 | TZA
154 | 3.254 | 0.337 | 0.608 | 0.177 | 0.112 | 0.224 | 0.106 | 1.5640000000000003 | 1.6899999999999997 | Bottom | SS | Africa | South Sudan | 11384393.0 | SSD
155 | 3.083 | 0.024 | 0.0 | 0.01 | 0.305 | 0.218 | 0.038 | 0.595 | 2.4880000000000004 | Bottom | CF | Africa | Central African Republic | 4709000.0 | CAF
156 | 2.905 | 0.091 | 0.627 | 0.145 | 0.065 | 0.149 | 0.076 | 1.153 | 1.7519999999999998 | Bottom | BI | Africa | Burundi | 9530434.0 | BDI

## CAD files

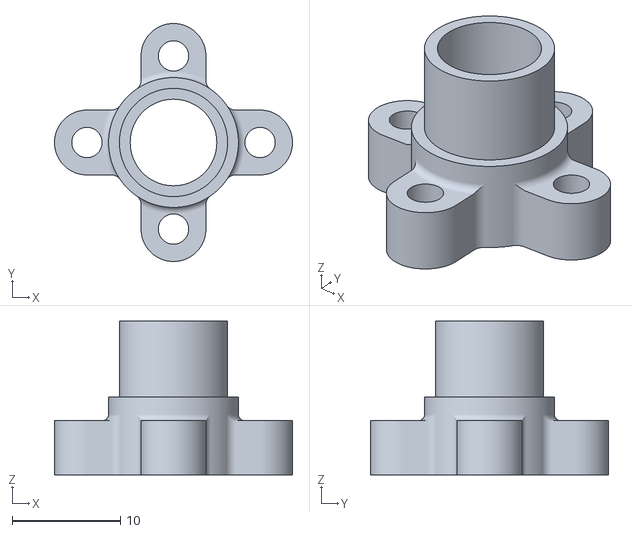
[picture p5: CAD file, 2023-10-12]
stl/motor/housing.stl
22.0 x 22.0 x 14.2

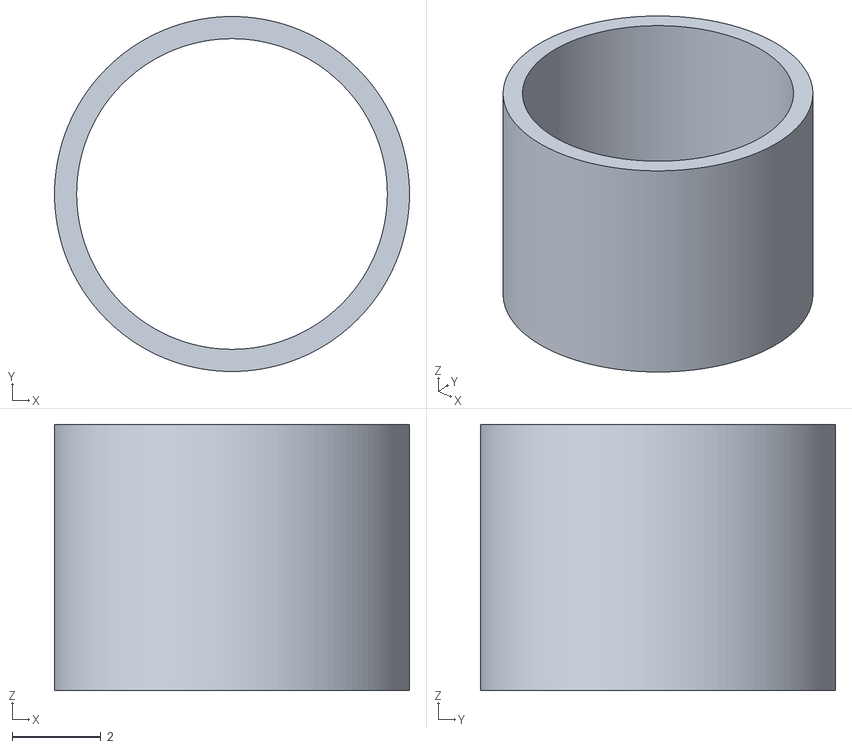
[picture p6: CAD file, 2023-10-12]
stl/motor/spacer.stl
8.00 x 8.00 x 6.00

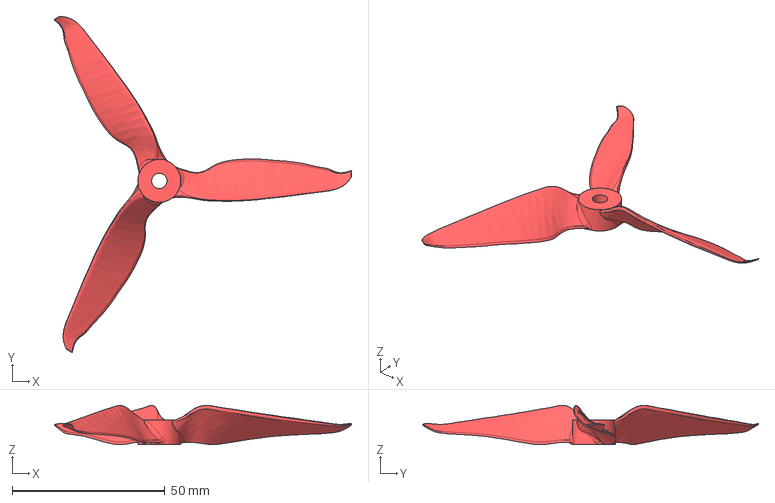
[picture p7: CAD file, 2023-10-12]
stl/motor/Propeller CW Puller.step
97.3 x 109.9 x 12.9 mm

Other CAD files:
stl/motor/Propeller CCW Puller.step
stl/motor/2207 motor.f3d

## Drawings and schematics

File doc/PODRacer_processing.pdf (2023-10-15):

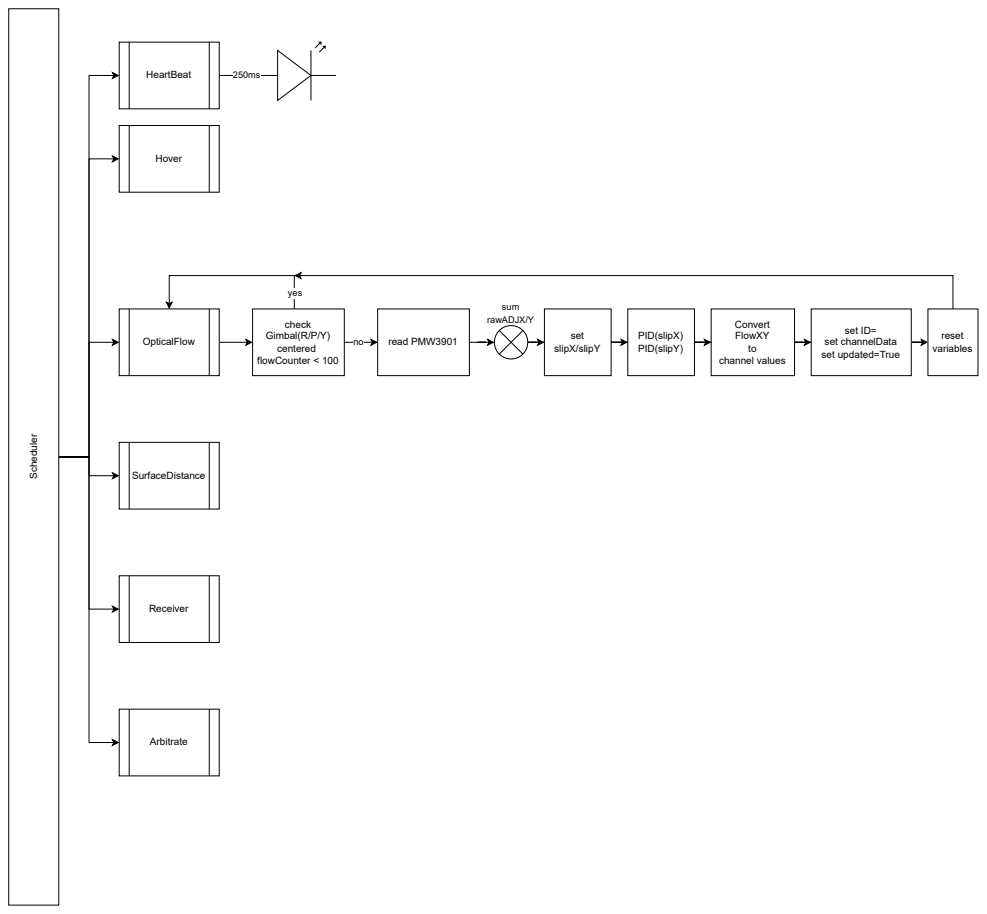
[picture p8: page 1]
HeartBeat; Hover; OpticalFlow; SurfaceDistance; Receiver; Scheduler; Arbitrate; yes; check Gimbal(R/P/Y) centered flowCounter < 100; read PMW3901; Convert FlowXY to channel values; sum rawADJX/Y; PID(slipX) PID(slipY); reset variables; set slipX/slipY

set ID=
set channelData
set updated=True

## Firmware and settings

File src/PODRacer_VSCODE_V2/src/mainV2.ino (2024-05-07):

/***********************************************************************************************



***********************************************************************************************/

// PODRacer use CooperativeTask mechanism
#include <CoopTaskBase.h>
#include <CoopTask.h>
#include <CoopSemaphore.h>
#include <CoopMutex.h>
#include <BasicCoopTask.h>
#include <assert.h>
#include "global.h"
#include "global_utils.h"
#include "globalvars.h"

// PODRacer Classes/Stuff
#include "Mixer.h"              // this is not a task; responsible to calculate new writings for receiver, based on all below tasks
#include "Receiver.h"           // this is not a task; responsible for reading/writing SBUS commands
#include "Logger.h"             // this is not a task; our logger class
#include "Blackbox.h"           // this is not a task; responsible to save data (blackbox) on SDCard
#include "WiFiData.h"           // this is not a task; responsible to save data (blackbox) on SDCard
#include "TaskBlink.h"          // task; responsible to generate blink-patterns
#include "TaskOpticalFlow.h"    // task; responsible to calculate new data based on the optical flow sensor
#include "TaskSurface.h"        // task; responsible to calculate new data based on both distance sensors
#include "TaskSteering.h"       // task; responsible to calculate a smooth steering
#include "TaskHover.h"          // task; responsible to calculate the hight of the PODRacer (hovering)



TaskList taskList ;
uint16_t ARMING_VALUE;

const char* _tname = "MAIN";         // used to log MAIN output

//HardwareSerial hsBus1(1);       // used by LIDAR Sensor in TaskSurface
HardwareSerial hsBus2(2);       // used by Receiver for SBUS

SLog logger(&Serial, 115200, LOGLEVEL);   // setup up our serial Logger


// TaskClasses
CoopTask<void>* taskBlink = nullptr;  
CoopTask<void>* taskHover = nullptr;  
CoopTask<void>* taskSurface = nullptr;  
CoopTask<void>* taskOFlow = nullptr;  
CoopTask<void>* taskSteer = nullptr;  
CoopTask<void>* taskIdle = nullptr;  

CoopSemaphore taskSema(1,1);            // start-value 1, one concurrend task taskSema(<number>,<concurrendTasks>)
Blackbox bb(&logger, BLACKBOX_CS_PIN);
Receiver receiver(&logger, "RECV", &taskSema, &hsBus2, 16, 17, true, "AEHRD23T");
Mixer mixer(&logger, "MIXER", &taskSema);


char buffer[300];
bool podracer_armed = false;
TaskData *tdr = nullptr;
TaskData *tdw = nullptr;

/***************************************************************/
/*                                                             */
/* all task do have this kind of function. This is a callback. */
/* from CoopTask. Every task need such a callback function     */
/*                                                             */
/* currently only this tasks are available                     */
/*  taskBlink     Blink patterns                               */
/*  taskHover     for hovering                                 */
/*  taskSteering  for steering ()                              */
/*  taskSurface   for measuring distance to survace            */
/*  taskOpticalFlow for measuring an optical flow              */
/***************************************************************/


/* RUN this callBack function for endless loop this task */
void callbackTaskBlinkPattern() {
  unsigned long lastMillis = millis();
  Serial.println("B1...");
  logger.info("callbackTaskBlinkPattern run...", true, _tname);
  BlinkPattern *obj = new BlinkPattern(&logger, "BLINK", TASK_BLINK);
  uint8_t blink_pattern = 0;
  obj->begin();
  for(;;) {
    blink_pattern=PATTERN_IDLE;                 // if nothing special blink to have a heart-beat signal
    if (receiver.isPreventArming()) {           // special blink pattern if arming is not possible
      Serial.println("Prevent");
      blink_pattern = PATTERN_PREVENTARMING;
    } else if (!receiver.isArmed()) {
        blink_pattern = PATTERN_DISARMED;       // blink pattern to show PODRacer is disarmed
    } else if (receiver.isArmed()) {
        blink_pattern = PATTERN_ARMED;          // blink pattern to show PODRacer is disarmed
    }
    obj->update(blink_pattern, ALLOW_LOGGING_BLINK);
    yield();
  }
}

/* RUN this callBack function for endless loop this task */
void callbackTaskHover() {
  unsigned long lastMillis = millis();
  TaskHover *obj = new TaskHover(&logger, "HOVER", TASK_HOVER, &taskSema);
  obj->begin(ALLOW_LOGGING_HOVER);
  mixer.addTask(obj, TASK_HOVER);
  for(;;) {
    // for hovering we have to set explizit the current hovering
    // value which was received by SBUS
    if (tdr != nullptr) {
      obj->setGlobalChannel(HOVERING, tdr->data.ch[HOVERING]);
    }
    obj->update(podracer_armed, ALLOW_LOGGING_HOVER);
    yield();
  }
}

/* RUN this callBack function for endless loop this task */
void callbackTaskSteering() {
  unsigned long lastMillis = millis();
  TaskSteering *obj = new TaskSteering(&logger, "STEER", TASK_STEERING, &taskSema);
  obj->begin(ALLOW_LOGGING_STEER);
  mixer.addTask(obj, TASK_STEERING);

  #if defined(USE_TASK_STEERING)
  for(;;) {


    
  }
  #endif
}

/* RUN this callBack function for endless loop this task */
void callbackTaskOpticalFlow() {
  unsigned long lastMillis = millis();
  TaskOpticalFlow *obj = new TaskOpticalFlow(&logger, "STEER", TASK_OPTICALFLOW, &taskSema);
  obj->begin(ALLOW_LOGGING_OFLOW);
  mixer.addTask(obj, TASK_OPTICALFLOW);
  for(;;) {

  }
}

/* RUN this callBack function for endless loop this task */
void callbackTaskSurface() {
  unsigned long lastMillis = millis();
  uint16_t err;
  HardwareSerial lidarSerial(1);
  TaskSurface *obj = new TaskSurface(&logger, "SDIST", TASK_SURFACEDISTANCE, &taskSema, &lidarSerial);
  obj->begin(ALLOW_LOGGING_SDIST);
  mixer.addTask(obj, TASK_SURFACEDISTANCE);
  for(;;) {
    if (obj->isInternalError()) {
      obj->update(podracer_armed, ALLOW_LOGGING_SDIST);
    }
    else {
      char bin[32];
      err = 0xCCF0;
      logger.convertValueToBinary(bin, sizeof(uint16_t), &err);
      sprintf(buffer, "*** TaskSurface error detected : [%s]", bin);
      logger.error(buffer, _tname);
      //logger.once_error(&log_once_);
    }
    yield();
  }
}

/*-----------------------------------------------------------------------------------------*/
//
//  Arduino SETUP 
//
/*-----------------------------------------------------------------------------------------*/

void setup() {
  while (!Serial);
  delay(100);
  #if !defined(ESP32)
    Serial.println("!!!!!!!!!!!!!!!!!!!!!!!!!!!");
    Serial.println("not running on ESP32 device");
    Serial.println("!!!!!!!!!!!!!!!!!!!!!!!!!!!");
    assert(0);
  #endif


  sprintf(buffer, "- PODRacer-FWVersion: %s", bb.FWVersion());

  logger.info("------------------------------------------------", true, _tname);
  logger.info(buffer, true, _tname);
  logger.info("------------------------------------------------", true, _tname);
  logger.info("setup in progress....", true, _tname);
  //bb.begin();
  mixer.begin();

  taskBlink = new CoopTask<void>(F("BLINK"), callbackTaskBlinkPattern);
  taskHover = new CoopTask<void>(F("HOVER"), callbackTaskHover);
  taskSurface = new CoopTask<void>(F("SDIST"), callbackTaskSurface);
  taskOFlow = new CoopTask<void>(F("OFLOW"), callbackTaskOpticalFlow);
  taskSteer = new CoopTask<void>(F("STEER"), callbackTaskSteering);

  logger.info("CoopTasks initialized, wakeup tasks...", true, _tname);
  if (taskBlink && TASK_WAKEUP_BLINK) { if (taskBlink->wakeup()) {logger.info("...taskBlink woke up", true, _tname);} else {logger.error("...error wakup taskBlink", _tname);}}
  if (taskHover && TASK_WAKEUP_HOVER) { if (taskHover->wakeup()) {logger.info("...taskHover woke up", true, _tname);} else {logger.error("...error wakup taskHover", _tname);}}
  if (taskSurface && TASK_WAKEUP_SDIST) { if (taskSurface->wakeup()) {logger.info("...taskSurface woke up", true, _tname);} else {logger.error("...error wakup taskSurface", _tname);}}
  if (taskOFlow && TASK_WAKEUP_SDIST) { if (taskOFlow->wakeup()) {logger.info("...taskOFlow woke up", true, _tname);} else {logger.error("...error wakup taskOFlow", _tname);}}
  if (taskSteer && TASK_WAKEUP_SDIST) { if (taskSteer->wakeup()) {logger.info("...taskSteer woke up", true, _tname);} else {logger.error("...error wakup taskSteer", _tname);}}
  logger.info("all tasks running", true, _tname);

  //logger.setVisualizerMode(0);
  logger.setVisualizerMode(LOG_OUTPUT_VISUALIZER_MODE);
  logger.info("setup finished", true, _tname);
}



/*-----------------------------------------------------------------------------------------*/
//
//  Arduino PROCESSING-LOOP 
//  
// This loop calls 
//  * read recevier SBUS-Data
//  * update tasks (this updates calculate their own task data)
//  * call mixer, the mixer calculate the next sbus-write sbus-data, based on task taskdata 
//  * write SBUS-Data based on mixer calculation
//  *    
/*-----------------------------------------------------------------------------------------*/
void loop() {
  //  in every loop we read the SBUS-Receiver
  tdr = tdw = nullptr;
  // read SBUS Data from receiver
  receiver.setMock(MOCK_RECEIVER_READ);
  receiver.read(tdr, ALLOW_LOGGING_RECEIVER);
  tdr = receiver.getTaskData();
  // set global arming-flag
  podracer_armed = receiver.isArmed() ;
  podracer_armed = tdr->data.is_armed ;

  // // run all tasks
  runCoopTasks(nullptr, nullptr, nullptr);

  // now we mix all data together
  // update all task data due to latest receiver data structure
  mixer.update(tdr, ALLOW_LOGGING_MIXER);
  // get the result from mixer
  tdw = mixer.getTaskData();
  // //
  // // // update SBUS-Receiver with a mixed signal
  receiver.write(tdw);
  yield();
}

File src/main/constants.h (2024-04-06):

#ifndef _CONSTANTS_H_
#define _CONSTANTS_H_

#define TEST_NO_TRANSMITTER_USED            // TEST - ATTENTION use this only to work withou transmiter



#define FW_VERSION_PATTERN "%02d.%02d.%02d"
#define FW_VERSION_MAJOR 0
#define FW_VERSION_MINOR 1
#define FW_VERSION_PATCH 0

#define BYTE_TO_BINARY_PATTERN  "%c%c%c%c%c%c%c%c"
#define BYTE_TO_BINARY_PATTERN2 "%c%c%c%c% c%c%c%c"
#define BYTE_TO_BINARY(byte)  \
  ((byte) & 0x80 ? '1' : '0'), \
  ((byte) & 0x40 ? '1' : '0'), \
  ((byte) & 0x20 ? '1' : '0'), \
  ((byte) & 0x10 ? '1' : '0'), \
  ((byte) & 0x08 ? '1' : '0'), \
  ((byte) & 0x04 ? '1' : '0'), \
  ((byte) & 0x02 ? '1' : '0'), \
  ((byte) & 0x01 ? '1' : '0') 


#define LOGLEVEL 3  // 3=Info, 4=Debug

// if you use the PODRacer Visualizer / Analyzer - please use this define and comment ALL LOG_xxxxx output
#define LOG_VISUALIZER


//#define LOG_TASK_ALL
//#define LOG_TASK_RECEIVER_W
//#define LOG_TASK_RECEIVER_RRAW
//#define LOG_TASK_RECEIVER_R
//#define LOG_TASK_RECEIVER
//#define LOG_TASK_MIXER_HOVER
//#define LOG_TASK_MIXER_SDIST
//#define LOG_TASK_MIXER_RPY
//#define LOG_TASK_MIXER_RECVW
//#define LOG_TASK_MIXER_OFLOW
//#define LOG_TASK_HOVER
//#define LOG_TASK_OPTICALFLOW
//#define LOG_TASK_SURFACE_LIDAR
//#define LOG_TASK_SURFACE_TOF
//#define LOG_TASK_SURFACE_BOTH        // both values 
//#define LOG_TASK_STEERING
//#define LOG_FILE_LOGGER
//#define USE_SERIAL_PLOTTER

//#define USE_SDIST_VL53L0        // only VL53L0 OR VL53L1 - not both
#define USE_SDIST_VL53L1      // only VL53L1 OR VL53L0 - not both

//-------------------------------------------------------------
// only used during implementing to test & check outputs
// all parts should used in real behaviour !
// hovering as base task can't be ignored
//
// Note: if below parts are commented, the behind task will work
//        and can output messages, and inside MIXER the results
//        from this task will be ignored
//-------------------------------------------------------------
#define USE_SDIST_OUTPUT         
//#define USE_OFLOW_OUTPUT
//#define USE_STEERING_OUTPUT
//-------------------------------------------------------------




//#define TEST_OPTICAL_FLOW



#define LED1 15
#define LED_BUILTIN 2
#define LOOP_TIME 10
#define PIN_PMW3901 5

//------------------------------------------------------------------------------------------------------------
// TASK_IDs are used to indicate a blink pattern
//------------------------------------------------------------------------------------------------------------
#define TASK_HB 0xFF
#define TASK_HOVER 1
#define TASK_OPTICALFLOW 2
#define TASK_SURFACEDISTANCE 3
#define TASK_FRONTDISTANCE 4
#define TASK_STEERING 5
#define TASK_RECEIVER 6
#define TASK_MIXER 7
#define TASK_EMERGENCY 8

//------------------------------------------------------------------------------------------------------------
// receivers toogle values around 1-5 +/- if nothing done by user activity
// this avoid false readings inside Receiver-class. As bigger the value is, as less sensitive your PODracer is around center gimbal position
//------------------------------------------------------------------------------------------------------------
#define RECEIVER_NOISE 5       // if normaly center pos should be 1500 (calibrated transmitter), mostley this value slip +/- 5 aournd this centerposition
                                // is used inside receiver to remove this slip

#define GIMBAL_CENTER_POSITION (int16_t)1500
#define GIMBAL_MIN (int16_t)1000
#define GIMBAL_MAX (int16_t)2000

#define ARMING_VALUE 1600     // everything above this value is armed

#define ROLL  0  // internal channel mapping set A(Roll) on position 0
#define PITCH 1  // dito for E(Pitch)
#define THRUST 7  // dito for T(Throttle) -> forward THRUST ESC -> we used the throttle gimbal for flying forward
#define YAW 3      // dito for R(Yaw)
#define ARMING 4   // ch5 for arming/disarming
#define AUX1 4
#define AUX2 5
#define AUX3 6
#define HOVERING 2     // hovering -> all 4 motors Throttle - flight controller manage this

// range interval around centerpositoin for A/E/Y
// this is used by sensors like OpticalFlow. All Values between value-CENTER_RANGE and value+CENTER_RANGE are used as "CENTER"
// this avoid very sensible gimbal movements. For a PODRacer this is ok, for real quad copters a totally NO_GO ;-)
// value is used for isGimbalMin/Max
#define CENTER_RANGE 50 



//------------------------------------------------------------------------------------------------------------
// Hovering
//------------------------------------------------------------------------------------------------------------
#define HOVER_ROLL GIMBAL_CENTER_POSITION   // default ch1
#define HOVER_PITCH GIMBAL_CENTER_POSITION  // default ch2
#define HOVER_YAW GIMBAL_CENTER_POSITION    // default ch4
#define HOVER_THRUST GIMBAL_MIN             // ch8 forward mapped used for ESC for EDF thrust nozzle
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

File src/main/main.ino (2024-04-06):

/**

Grundlegende Idee

Es wird eine Subsumption Vorgehensweise implementiert. Im Hintergrund läuft
einer cooperativer Scheduler 

Subsumption
Wiederkehrende Funktionen werden als TASKS definiert.
Alle tasks werden in einer "Mixer-Funktion" ausgewertet und priorisiert

Im Prinzip wird die Ausgabe eines geringer priorisierten Tasks durch den nächst
höheren Task überschrieben

Beispiel
Task1 = CRUISE (der PodRacer fliegt einfach geradeaus und hält die Höhe)
Task2 = MovementControl (kontrolliert den OpticalFlowSensor)
Task3 = SurfaceDistance1 (kontrolliert die Höhe über Grund mit dem TFMiniLidar)
Task4 = SurfaceDistance2 (kontrolliert die Höhe über Grund mit dem VL53L1)
Task5 = Receiver - kontrolliert den Empfang von Daten und die Weiterleitung an den FC

Mixer (Priorisierung)


**/

// Include CoopTask since we want to manage multiple tasks.
#include <CoopTaskBase.h>
#include <CoopTask.h>
#include <CoopSemaphore.h>
#include <CoopMutex.h>
#include <BasicCoopTask.h>
#include <assert.h>
#include "Receiver.h"
#include "Mixer.h"
#include "OpticalFlow.h"
#include "SurfaceDistance.h"
#include "SimpleLog.cpp"
#include "Hover.h"
#include "Steering.h"
#include "BlinkPattern.h"
#include "Blackbox.h"
#include "constants.h"

char * _tname = "MAIN";
int taskToken = 1;
bool showDisarmed = true;

HardwareSerial hsBus2(2);

SLog        logger(&Serial, 115200, LOGLEVEL);
//SLog        logger(&hsBus2, 115200, LOGLEVEL);

Blackbox    bb(&logger, BLACKBOX_CS_PIN);

CoopTask<void>* blinkpatternTask = nullptr;
CoopTask<void>* receiverCtrlTask = nullptr;
CoopTask<void>* movementCtrlTask = nullptr;
CoopTask<void>* hoverCtrlTask = nullptr;
CoopTask<void>* steeringCtrlTask = nullptr;
CoopTask<void>* surfaceDistCtrlTask = nullptr;
CoopTask<void>* mixerCtrlTask = nullptr;


//CoopTask<void>* blackboxCtrlTask = nullptr;

/** 
This semaphore is used to avoid concurrent access to the receives data array during updateing this array
Receiver.cpp set and reset this semaphore. is set, other task can not read the internal data array via getData()
**/
CoopSemaphore taskSema(1, 1);
HardwareSerial lidarSerial(1);      // Parameter 1 => Serial1.


BlinkPattern blinkP(TASK_HB, &logger);
Hover hover(TASK_HOVER, &logger,&bb, nullptr);
SurfaceDistance distance(TASK_SURFACEDISTANCE, &logger, &lidarSerial, &bb, nullptr);
OpticalFlow flow(TASK_OPTICALFLOW, &logger, PIN_PMW3901, &bb, nullptr);
Steering steering(TASK_STEERING, &logger, &bb, nullptr);
Receiver receiver(TASK_RECEIVER, &logger, &Serial2, 16, 17, true, &bb, nullptr);
Mixer mixer(TASK_MIXER, &logger, &bb);

//Blackbox bb(TASK_MIXER, &logger, CS_PIN);

// some messages should only be print one time
// if true, print otherweise do not print again
bool log_once_disarmed = true;


//Receiver *receiver;
uint8_t blink_pattern = 0;

// Task: HeartBeat (1 second)
void BlinkPatternFunction() {
  blinkP.begin(&blink_pattern);
  char buffer[100];
  for(;;) {
    blink_pattern = 0;
    if (receiver.isPreventArming()) {
      blink_pattern = PATTERN_PREVENTARMING;
    } else if (!receiver.isArmed()) {
      blink_pattern = PATTERN_DISARMED;
    }
    blinkP.update(blink_pattern);
    yield();
  }
}

// Task: use PMW3901 optical flow sensor
void MovementControlFunction() {
//  taskSema.wait();

  unsigned long lastMillis = millis();
  int16_t deltaX,deltaY;
  if (flow.begin(&receiver) == false) {
    logger.error("MAIN : can't start OpticalFlow", _tname);
    return;
  }
  for(;;) {
    if (!flow.hasError()) {
      //Serial.println("run MovementControlFunction");
      flow.update();
      //flow.readMotionCount(&deltaX, &deltaY);
      if ((millis() - lastMillis) > LOOP_TIME) {
        yield();
      }
      delay(LOOP_TIME);
    }
  }
}


// Primary Task Hovering is the base functionality of the complete PODRacer System
// 
void HoverControlFunction() {
  unsigned long lastMillis = millis();
  if (hover.begin(&receiver) == false ) {
    logger.error("MAIN : can't start Hover object", _tname);
    return;
  }
  for(;;) {
    //Serial.println("HoverControlFunction");
    if (!hover.hasError()) {
      #if defined(LOG_TASK_MIXER_HOVER)
        logger.debug("hover.update()");
      #endif
      hover.update();
      if ((millis() - lastMillis) > LOOP_TIME) {
        yield();
      }
    }
    else {
      logger.error("HOVER return error", _tname);
    }
  }
  delay(LOOP_TIME);
}

// Primary Task Hovering is the base functionality of the complete PODRacer System
// 

// Steering
// 
void SteeringControlFunction() {

  unsigned long lastMillis = millis();
  if (steering.begin(&receiver) == false ) {
    logger.error("MAIN : can't start Steering object", _tname);
    return;
  }

  for(;;) {
    if (!steering.hasError()) {
      //steering.update();
      if ((millis() - lastMillis) > LOOP_TIME) {
        yield();
      }
      delay(LOOP_TIME);
    }
  }

}

// 
void SurfaceDistanceControlFunction() {
  unsigned long lastMillis = millis();
    if (distance.begin(&receiver) == false ) {
      logger.error("MAIN : can't start SurfaceDistance object", _tname);
      return;
    }
  for(;;) {
    if (!distance.hasError()) {
      distance.update();
      if ((millis() - lastMillis) > LOOP_TIME) {
        yield();
      }
      delay(LOOP_TIME);
    }
    else {
      yield();
    }

  }
}

// Task: Mixer 
void MixerControlFunction() {
  char buffer[100];
  unsigned long lastMillis = millis();
  if (&receiver) {
    if (!mixer.begin(&receiver)) {
      logger.error("MAIN : can't start mixer object", _tname);
    }
  }
  else {
    logger.error("mixer.begin() - no receiver object", _tname);
  }
  bool updated = false;
  for(;;) {
    updated=false;
    if (receiver.isArmed()) {
      if (hover.isUpdated()) {/*Serial.println("MIXER(HOVER)");*/ mixer.update(&hover); updated=true;}
      if (distance.isUpdated()) {/*Serial.println("MIXER(SDIST)");*/ mixer.update(&distance); updated=true;}  
      if (steering.isUpdated()) {mixer.update(&steering); updated=true;} 
      if (flow.isUpdated()) {mixer.update(&flow); updated=true;}  
      // if nothing above was updated, than do an explicit update()
      if (!updated) {mixer.update();}
      log_once_disarmed = true;
      if ((millis() - lastMillis) > LOOP_TIME) {
        yield();
      } else {
        delay(LOOP_TIME);
      }


    }
    else {
      if (log_once_disarmed) {
        logger.warn("\n\n********************\nDISARMED\n********************\n", _tname);
        log_once_disarmed = false;
      }
    }
    if ((millis() - lastMillis) > LOOP_TIME) {
      yield();
    }
    delay(LOOP_TIME);

  }
}
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

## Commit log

2023-10-12 TF series LiDARinterfacing with esp32
2023-10-16 Class template SurfaceDistance
    for TFMiniLidar & VH53L1 ToF Sensor
2023-10-20 PID in OpticalFlow
    Probleme bei Abfrage isGimbalCentered
    [OpticalFlow.h, constants.h]
2023-10-22 HardwareSerial for Lidar
2023-10-29 nightly, working on arming & preventArming
    [constants.h, main.ino]
2023-11-16 sdist bugfix, output prep for serial-plotter
    [constants.h]
2023-11-28 nightly with visualizer (python)
    [country_indicators.csv, finance-charts-apple.csv, gapminder2007.csv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]
